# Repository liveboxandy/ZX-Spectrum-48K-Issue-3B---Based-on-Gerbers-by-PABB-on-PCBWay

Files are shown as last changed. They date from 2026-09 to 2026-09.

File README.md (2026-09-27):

# ZX-Spectrum 48K Issue 3B - Based on Gerbers by PABB on PCBWay

KiCAD created files for the ZX Spectrum 48K Issue 3B designed by Sinclair Research Ltd - Based on PABB Gerbers

Original Gerbers by PABB downloadable via PCBWay.

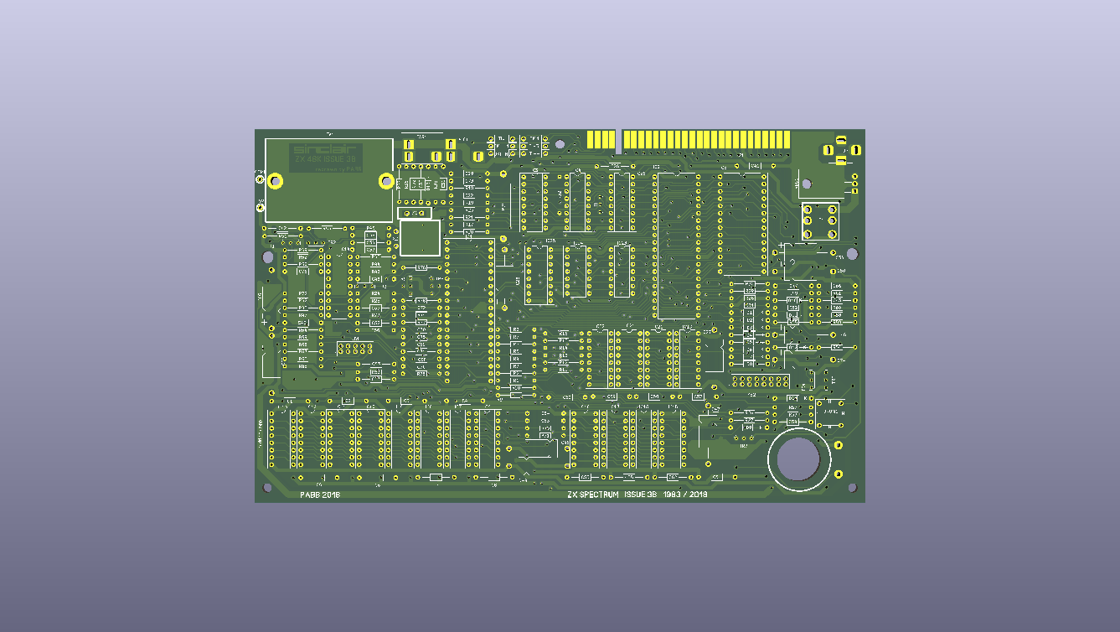
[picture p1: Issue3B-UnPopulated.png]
Unpopulated PCB


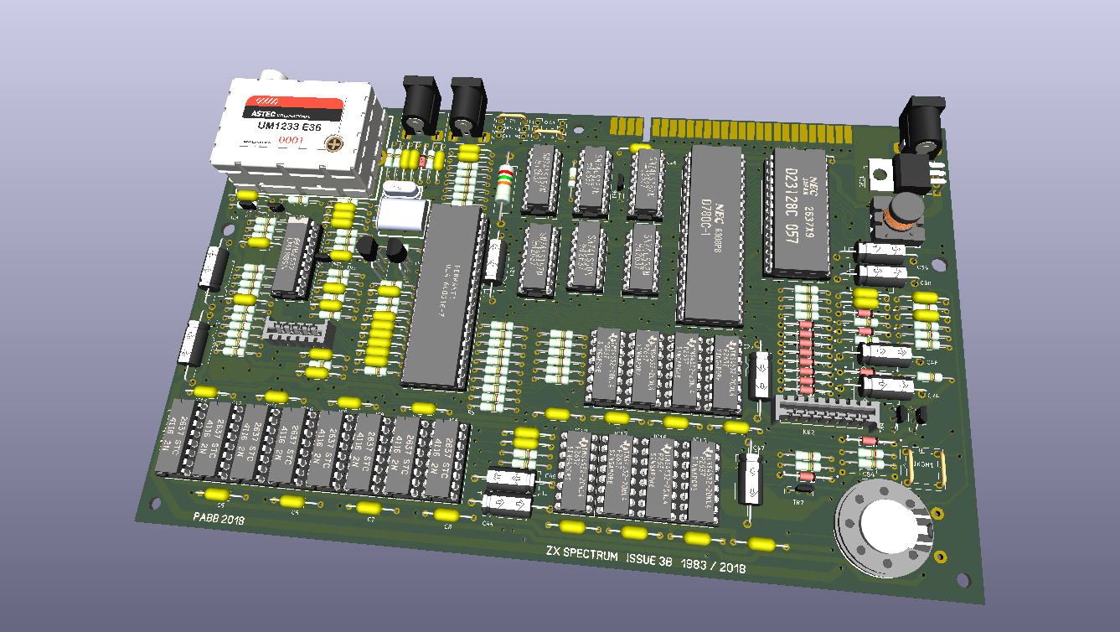
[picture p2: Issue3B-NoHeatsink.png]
Populated PCB No Heatsink


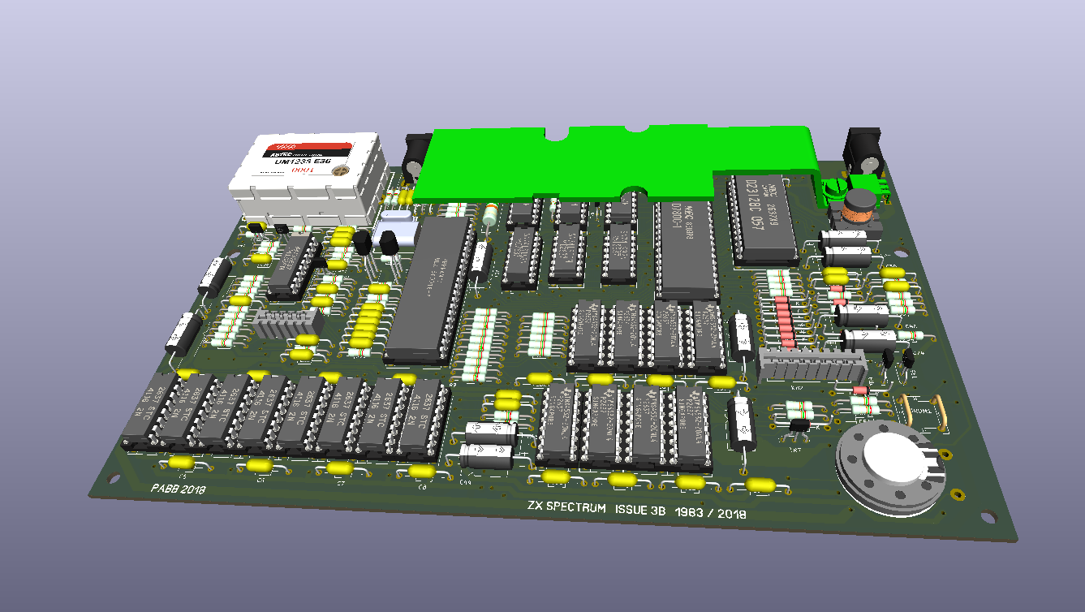
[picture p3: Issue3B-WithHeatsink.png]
Populated PCB With Heatsink


See https://www.pcbway.com/project/shareproject/ZX_Spectrum_48_Issue_3B_Redrawn.html

Only the gerbers are available on PCBWay. No Schematic.

Schematic created from available schematics with corrections using Service Guide mods and PCB layout. 

Where differences were seen the PCB layout took preference.

This was only done in order to create an assist in debugging.

I would NOT use these gerbers to get a PCB manufactured without a lot more checking first.

For the following ULA 6C001 make the following changes,

R47 to 1K,
R49 to 10K,
R56 to 1K,
R63 to 1K.

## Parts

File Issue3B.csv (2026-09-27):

Reference | Qty | Value | DNP | Exclude from BOM | Exclude from Board | Footprint | Datasheet
C1,C2,C3,C4,C5,C6,C7,C8,C26,C29,C30,C33,C40,C41,C42,C48,C55,C56,C57,C58,C59,C60,C61,C62,C66,C76 | 26 | 47nF |  |  |  | Mod:C_Axial_L3.8mm_D2.6mm_P12.70mm_Horizontal | https://www.vishay.com/doc?45164
C25 | 1 | 22uF |  |  |  | Mod:CP_Axial_L11.0mm_D6.0mm_P20.00mm_Horizontal
C27 | 1 | 1uF |  |  |  | Mod:CP_Axial_L11.0mm_D6.0mm_P20.00mm_Horizontal
C28,C34,C47,C50,C65 | 5 | 22uF |  |  |  | Mod:CP_Axial_L11.0mm_D6.0mm_P20.32mm_Horizontal | https://www.cde.com/resources/catalogs/TTA.pdf
C31,C32 | 2 | 100nF |  |  |  | Mod:C_Axial_L3.8mm_D2.6mm_P12.40mm_Horizontal | https://www.vishay.com/doc?45164
C35 | 1 | 10nF |  |  |  | Mod:C_Axial_L3.8mm_D2.6mm_P12.40mm_Horizontal | https://www.vishay.com/doc?45164
C37,C38 | 2 | 33pF |  |  |  | Mod:C_Axial_L3.8mm_D2.6mm_P12.70mm_Horizontal | https://www.vishay.com/doc?45164
C39 | 1 | 10nF |  |  |  | Mod:C_Axial_L3.8mm_D2.6mm_P12.70mm_Horizontal | https://www.vishay.com/doc?45164
C43,C68,C69,C70,C71,C75,C77 | 7 | 100nF |  |  |  | Mod:C_Axial_L3.8mm_D2.6mm_P12.70mm_Horizontal | https://www.vishay.com/doc?45164
C44,C45 | 2 | 100uF |  |  |  | Mod:CP_Axial_L11.0mm_D6.0mm_P20.32mm_Horizontal | https://www.cde.com/resources/catalogs/TTA.pdf
C46 | 1 | 1uF |  |  |  | Mod:CP_Axial_L11.0mm_D6.0mm_P20.32mm_Horizontal | https://www.cde.com/resources/catalogs/TTA.pdf
C49 | 1 | 560pF |  |  |  | Mod:C_Axial_L3.8mm_D2.6mm_P12.70mm_Horizontal | https://www.vishay.com/doc?45164
C52,C53 | 2 | 150pF |  |  |  | Mod:C_Axial_L3.8mm_D2.6mm_P12.70mm_Horizontal | https://www.vishay.com/doc?45164
C54 | 1 | 470pF | DNP |  |  | Mod:C_Axial_L3.8mm_D2.6mm_P12.70mm_Horizontal | https://www.vishay.com/doc?45164
C63 | 1 | 47pF |  |  |  | Mod:C_Axial_L3.8mm_D2.6mm_P12.70mm_Horizontal | https://www.vishay.com/doc?45164
C64,C67 | 2 | 100pF |  |  |  | Mod:C_Axial_L3.8mm_D2.6mm_P12.70mm_Horizontal | https://www.vishay.com/doc?45164
C72,C73 | 2 | 16pF |  |  |  | Mod:C_Axial_L3.8mm_D2.6mm_P12.70mm_Horizontal | https://www.vishay.com/doc?45164
C74 | 1 | 4.7uF |  |  |  | Mod:CP_Axial_L11.0mm_D6.0mm_P20.32mm_Horizontal | https://www.cde.com/resources/catalogs/TTA.pdf
D1,D2,D3,D4,D5,D6,D7,D8,D9,D11,D12 | 11 | 1N4148 |  |  |  | Mod:D_DO-35_SOD27_P12.70mm_Horizontal
D13 | 1 | 1N4148 |  |  |  | Mod:D_DO-35_SOD27_P12.40mm_Horizontal
D15 | 1 | BA157 |  |  |  | Mod:D_DO-35_SOD27_P12.70mm_Horizontal
D16 | 1 | BZX85C5V1 |  |  |  | Mod:D_DO-35_SOD27_P12.70mm_Horizontal
E1 | 1 | Edge_Connector |  |  |  | Mod:Edge Connector
EAR1 | 1 | EAR1 |  |  |  | Mod:3.5mm_socket
IC1 | 1 | ULA |  |  |  | Mod:DIP-40_W15.24mm_Socket
IC2 | 1 | Z80 |  |  |  | Mod:DIP-40_W15.24mm_Socket
IC3,IC4,IC25,IC26 | 4 | LS157 |  |  |  | Mod:DIP-16_W7.62mm_Socket
IC5 | 1 | ROM |  |  |  | Mod:DIP-28_W15.24mm_Socket
IC6,IC7,IC8,IC9,IC10,IC11,IC12,IC13 | 8 | 4116 |  |  |  | Mod:DIP-16_W7.62mm_Socket
IC14 | 1 | LM1889 |  |  |  | Mod:DIP-18_W7.62mm_Socket
IC15,IC16,IC17,IC18,IC19,IC20,IC21,IC22 | 8 | 4532 |  |  |  | Mod:DIP-16_W7.62mm_Socket
IC23 | 1 | LS32 |  |  |  | Mod:DIP-14_W7.62mm_Socket | http://www.ti.com/lit/gpn/sn74ls00
IC24 | 1 | LS00 |  |  |  | Mod:DIP-14_W7.62mm_Socket | http://www.ti.com/lit/gpn/sn74ls00
J7 | 1 | Barrel_Jack_MountingPin |  |  |  | Mod:BarrelJack_Horizontal | ~
JROM1 | 1 | JROM |  |  |  | Mod:ROM_WireLink
KB1 | 1 | Keyboard5 |  |  |  | Mod:Keyboard5
KB2 | 1 | Keyboard8 |  |  |  | Mod:Keyboard8
LS1 | 1 | Speaker |  |  |  | Mod:Speaker | ~
MIC1 | 1 | MIC1 |  |  |  | Mod:3.5mm_socket
OKI-H1 | 1 | OKI-H |  |  |  | Mod:WireLink
OKI-L1 | 1 | OKI-L |  |  |  | Mod:WireLink
OKI1 | 1 | OKI |  |  |  | Mod:WireLink
R1,R2,R3,R4,R5,R6,R7,R8,R26,R27,R78 | 11 | 470 |  |  |  | Mod:R_Yageo_L3.6mm_D1.6mm_P12.70mm_Horizontal
R9,R10,R11,R12,R13,R14,R15,R16 | 8 | 8k2 |  |  |  | Mod:R_Yageo_L3.6mm_D1.6mm_P12.70mm_Horizontal
R17,R18,R19,R20,R21,R22,R23,R57 | 8 | 330 |  |  |  | Mod:R_Yageo_L3.6mm_D1.6mm_P12.70mm_Horizontal
R24,R73 | 2 | 1k |  |  |  | Mod:R_Yageo_L3.6mm_D1.6mm_P12.70mm_Horizontal
R25 | 1 | 180 |  |  |  | Mod:R_Yageo_L3.6mm_D1.6mm_P12.70mm_Horizontal
R28,R29,R30,R49,R65,R66,R67,R68,R69,R72,R74,R75 | 12 | 10K |  |  |  | Mod:R_Yageo_L3.6mm_D1.6mm_P12.70mm_Horizontal
R31 | 1 | 220K |  |  |  | Mod:R_Yageo_L3.6mm_D1.6mm_P12.70mm_Horizontal
R32 | 1 | 100 |  |  |  | Mod:R_Yageo_L3.6mm_D1.6mm_P12.70mm_Horizontal
R33 | 1 | 680 |  |  |  | Mod:R_Yageo_L3.6mm_D1.6mm_P12.70mm_Horizontal
R34 | 1 | 15 |  |  |  | Mod:R_Axial_DIN0516_L15.5mm_D5.0mm_P22.60mm_Horizontal
R35 | 1 | 10K |  |  |  | Mod:R_Yageo_L3.6mm_D1.6mm_P12.40mm_Horizontal
R36 | 1 | 680 |  |  |  | Mod:R_Yageo_L3.6mm_D1.6mm_P12.40mm_Horizontal
R37 | 1 | 1K |  |  |  | Mod:R_Yageo_L3.6mm_D1.6mm_P12.40mm_Horizontal
R42,R45,R46,R47,R56,R58,R63,R76,R77 | 9 | 1K |  |  |  | Mod:R_Yageo_L3.6mm_D1.6mm_P12.70mm_Horizontal
R43 | 1 | 3K |  |  |  | Mod:R_Yageo_L3.6mm_D1.6mm_P12.70mm_Horizontal
R44 | 1 | 5K1 |  |  |  | Mod:R_Yageo_L3.6mm_D1.6mm_P12.70mm_Horizontal
R48,R51,R52 | 3 | 2K2 |  |  |  | Mod:R_Yageo_L3.6mm_D1.6mm_P12.70mm_Horizontal
R50 | 1 | 4K7 |  |  |  | Mod:R_Yageo_L3.6mm_D1.6mm_P12.70mm_Horizontal
R53 | 1 | 390R |  |  |  | Mod:R_Yageo_L3.6mm_D1.6mm_P12.70mm_Horizontal
R54 | 1 | 100K |  |  |  | Mod:R_Yageo_L3.6mm_D1.6mm_P12.70mm_Horizontal
R55 | 1 | 56 |  |  |  | Mod:R_Yageo_L3.6mm_D1.6mm_P12.70mm_Horizontal
R59 | 1 | 1K8 |  |  |  | Mod:R_Yageo_L3.6mm_D1.6mm_P12.70mm_Horizontal
R60 | 1 | 68R |  |  |  | Mod:R_Yageo_L3.6mm_D1.6mm_P12.70mm_Horizontal
R61,R62,R64 | 3 | 15 |  |  |  | Mod:R_Yageo_L3.6mm_D1.6mm_P12.70mm_Horizontal
R70,R71 | 2 | 220 |  |  |  | Mod:R_Yageo_L3.6mm_D1.6mm_P12.70mm_Horizontal
REG1 | 1 | L7805 |  |  |  | Mod:TO-220-3_Horizontal_TabDown
T1 | 1 | Transformer_1P_1S |  |  |  | Mod:Coil
TI-3 | 1 | TI-3 |  |  |  | Mod:WireLink
TI-4 | 1 | TI-4 |  |  |  | Mod:WireLink
TI1 | 1 | TI |  |  |  | Mod:WireLink
TR1,TR2,TR3,TR6 | 4 | ZTX313 |  |  |  | Mod:TO-92Flat
TR4 | 1 | ZTX650 |  |  |  | Mod:TO-92Flat
TR5 | 1 | ZTX315 |  |  |  | Mod:TO-92Flat
TR7 | 1 | ZTX450 |  |  |  | Mod:TO-92Flat
TR8,TR9 | 2 | BC184 |  |  |  | Mod:TR9
TV1 | 1 | TV |  |  |  | Mod:Modulator
X1 | 1 | 14Mhz |  |  |  | Mod:X1
X2 | 1 | 4.43Mhz |  |  |  | Mod:X2

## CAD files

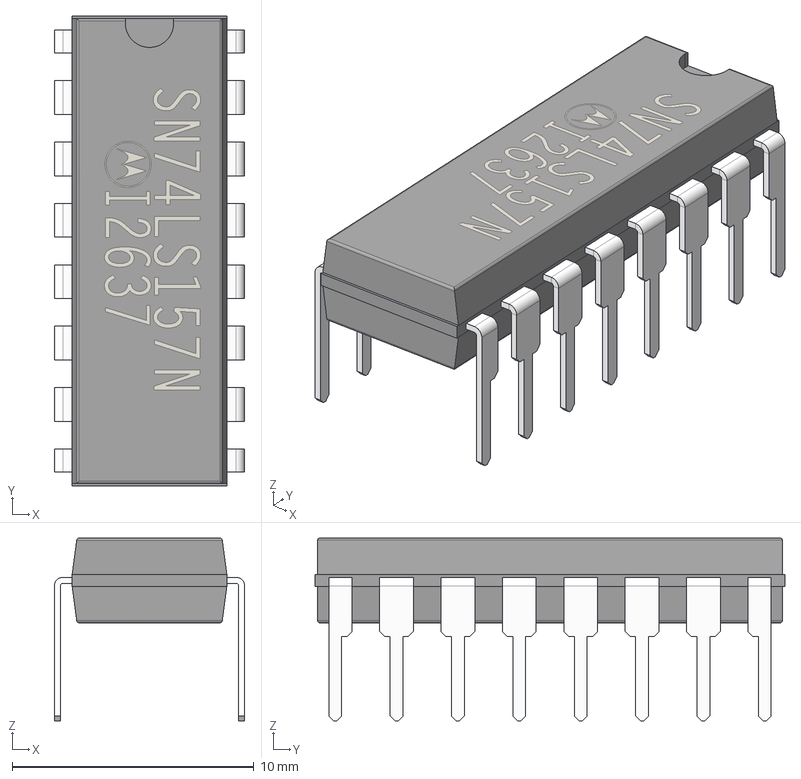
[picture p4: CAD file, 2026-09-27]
STPS/MOT_SN74LS157N.step
7.87 x 19.5 x 7.57 mm
Basic - DIP 7.62 v3
DIP Pin 14-20 v3
DIP Pin 14-20 v3(Mirror)

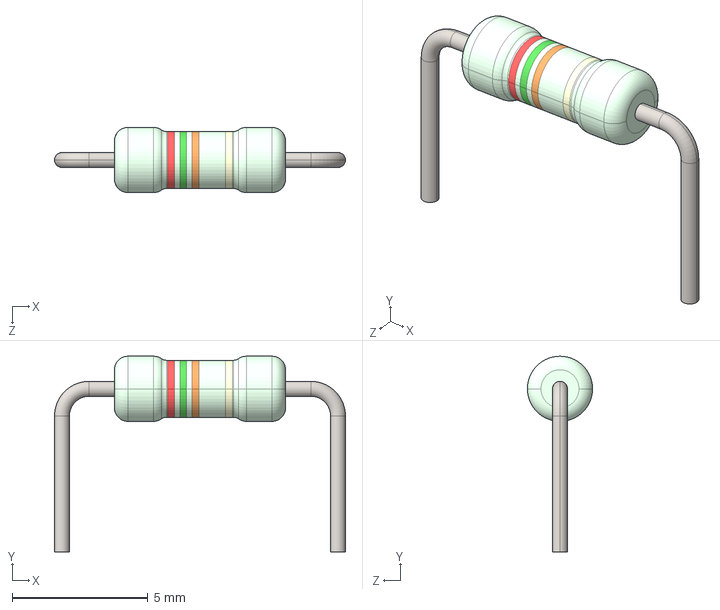
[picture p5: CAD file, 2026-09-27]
STPS/Resistor-0207-6.3x2.4x10.16.STEP
10.7 x 7.20 x 2.40 mm

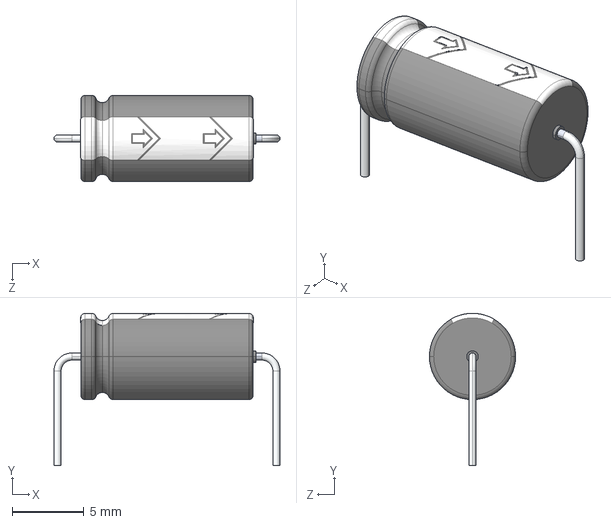
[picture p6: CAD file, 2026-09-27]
STPS/CP 13x5x0.5x15.24.STEP
15.7 x 10.6 x 6.00 mm

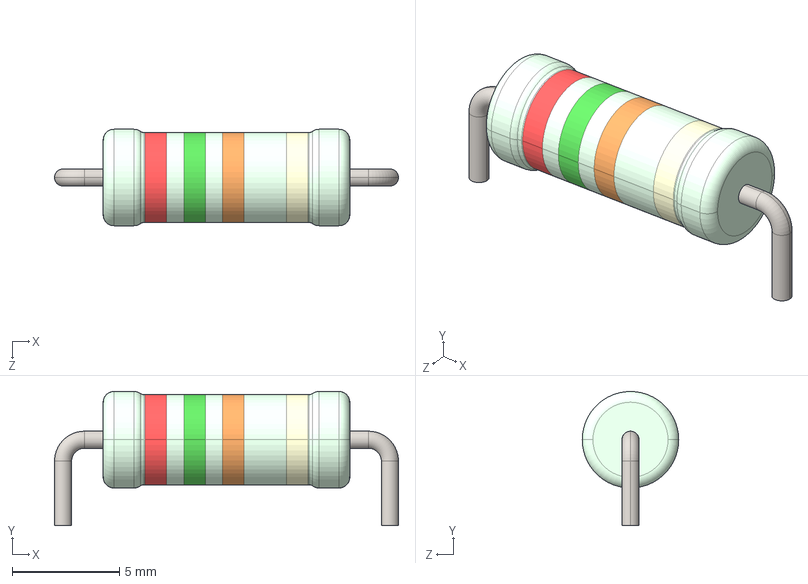
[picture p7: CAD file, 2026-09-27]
STPS/Resistor-0414-11.5x4.5x15.24x3.STEP
16.0 x 6.25 x 4.50 mm

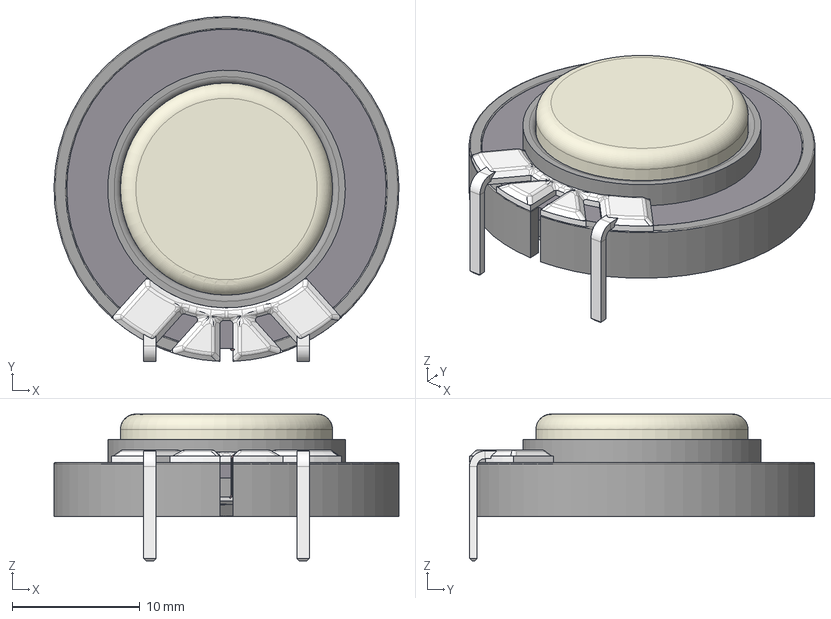
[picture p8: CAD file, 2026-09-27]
STPS/ZX Spectrum 48k Speaker.step
27.0 x 27.0 x 11.5 mm
Magnet
Soldering
pins
Plastic Film
Copper Wire

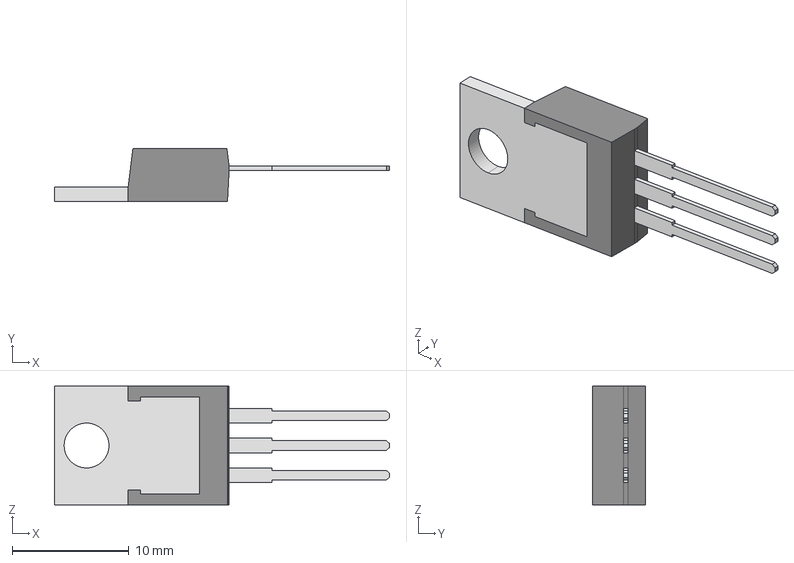
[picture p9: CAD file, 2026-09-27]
STPS/LM7805CT_NOPB.stp
28.7 x 4.57 x 10.2 mm
T03B_BODY
T03B_LEAD x 3
T03B_HS

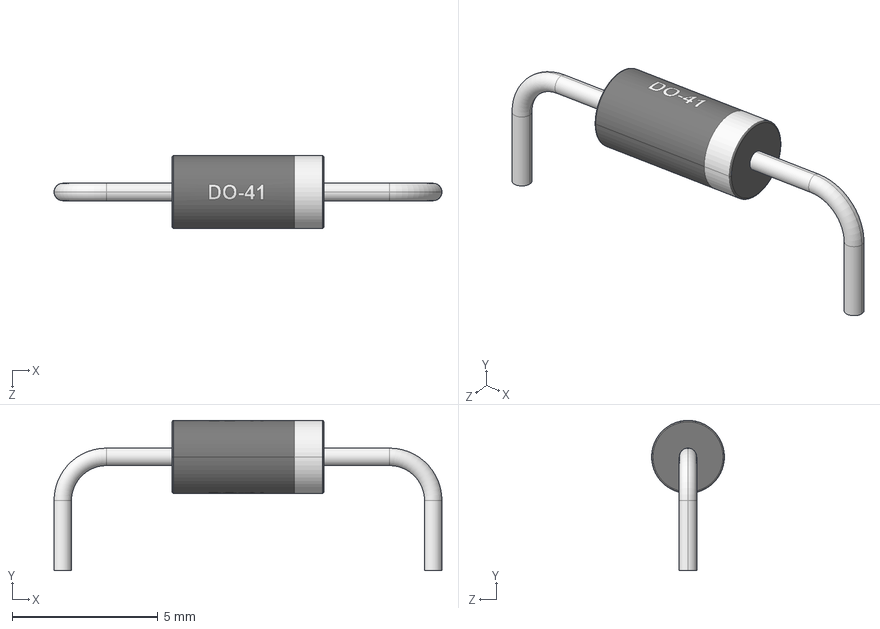
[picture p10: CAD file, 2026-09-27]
STPS/DO-41-5.10x2.60x12.70.STEP
13.3 x 5.15 x 2.50 mm

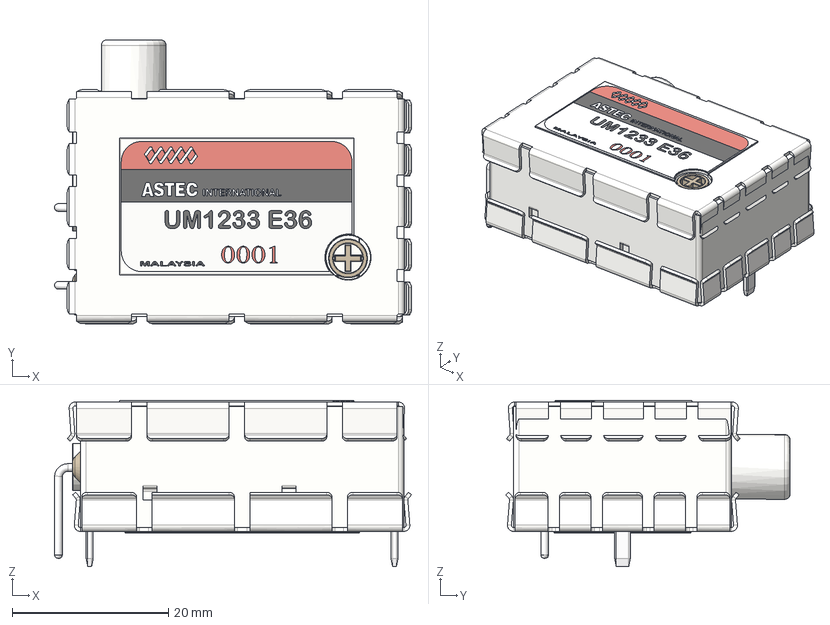
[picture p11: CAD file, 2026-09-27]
STPS/RF MOD Astec UM1233 E36.step
45.7 x 36.4 x 21.3 mm
Metal Body
Lid Bottom
Lid Top

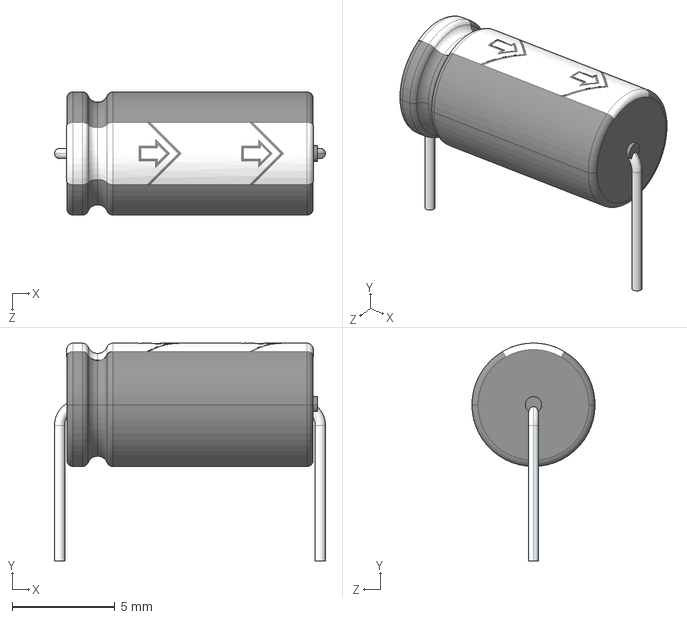
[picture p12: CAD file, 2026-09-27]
STPS/CP 13x5x0.5x12.70.STEP
13.2 x 10.6 x 6.00 mm

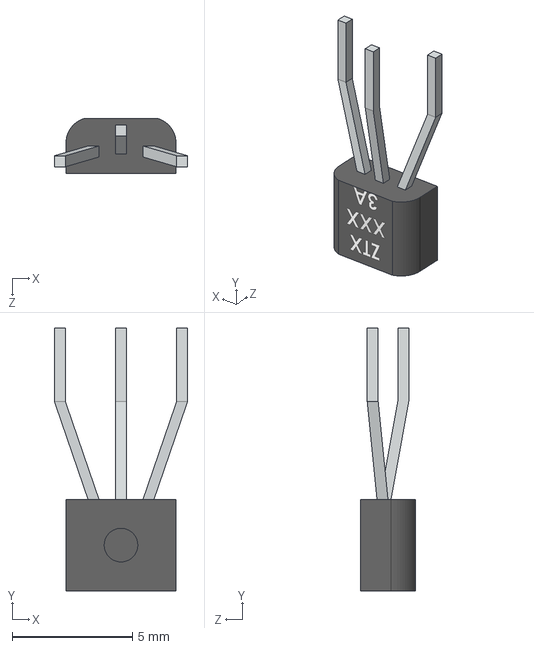
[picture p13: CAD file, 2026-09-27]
STPS/ZTXxxx Kinked Triangle.STEP
5.54 x 10.9 x 2.29 mm

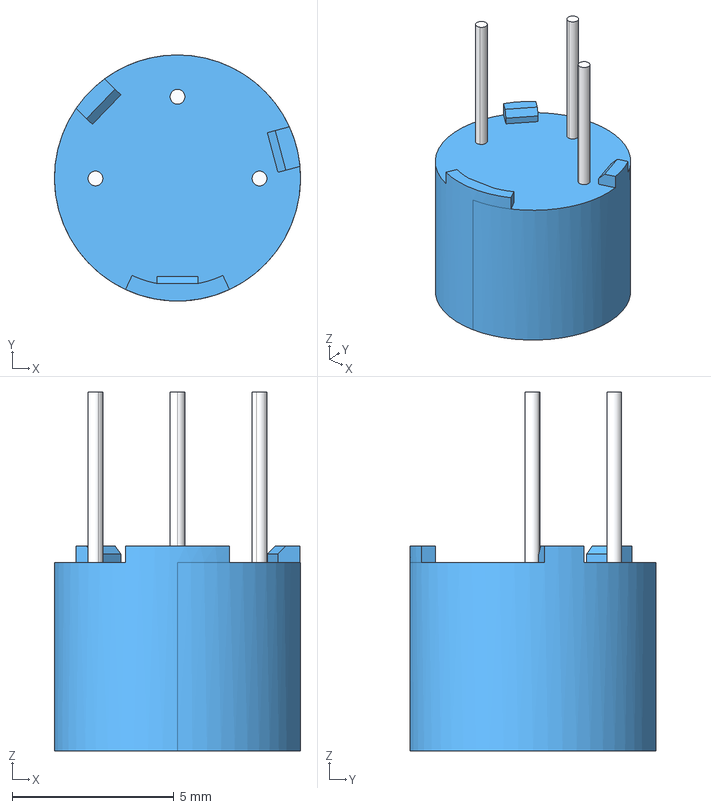
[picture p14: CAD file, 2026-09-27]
STPS/Pot 3339P-1-222LF.stp
7.62 x 7.62 x 11.1 mm

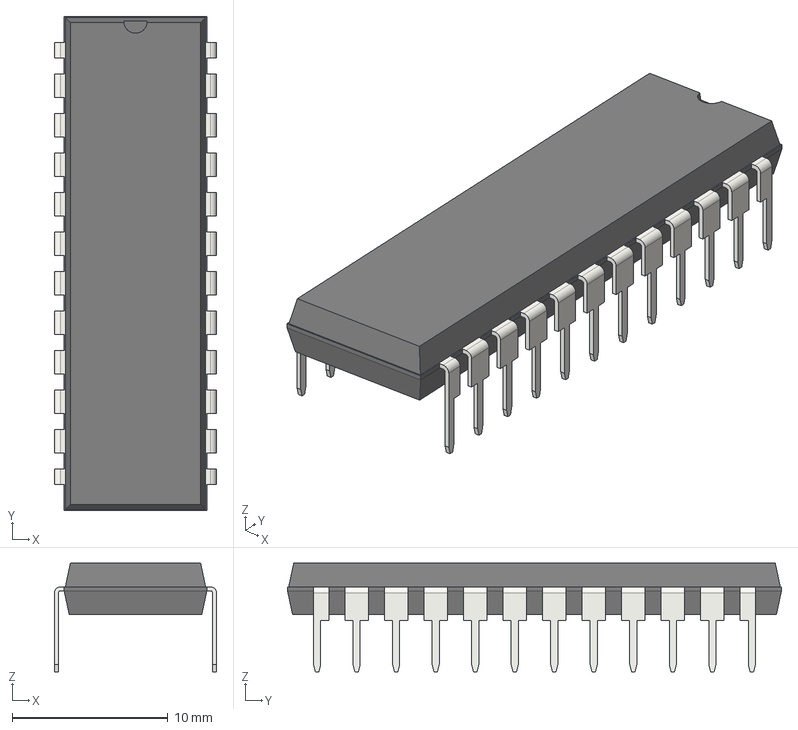
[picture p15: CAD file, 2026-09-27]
STPS/DIP-24_W10.16mm.step
10.4 x 31.8 x 6.98 mm

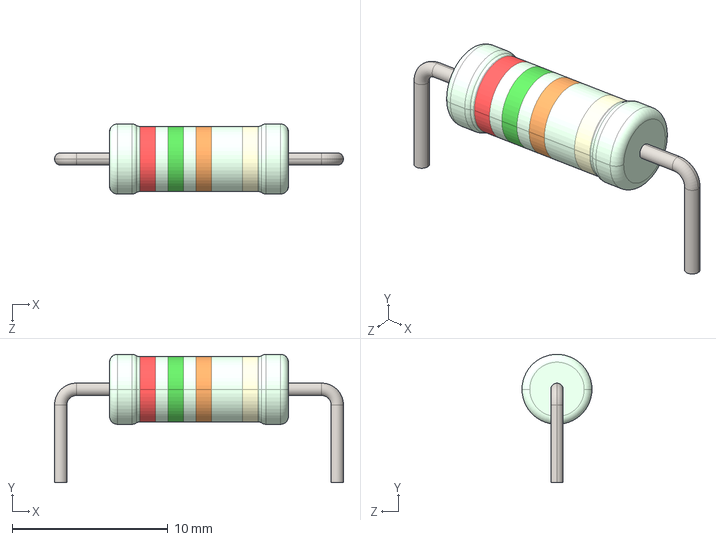
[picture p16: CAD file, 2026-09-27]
STPS/Resistor-0414-11.5x4.5x17.78.STEP
18.6 x 8.25 x 4.50 mm

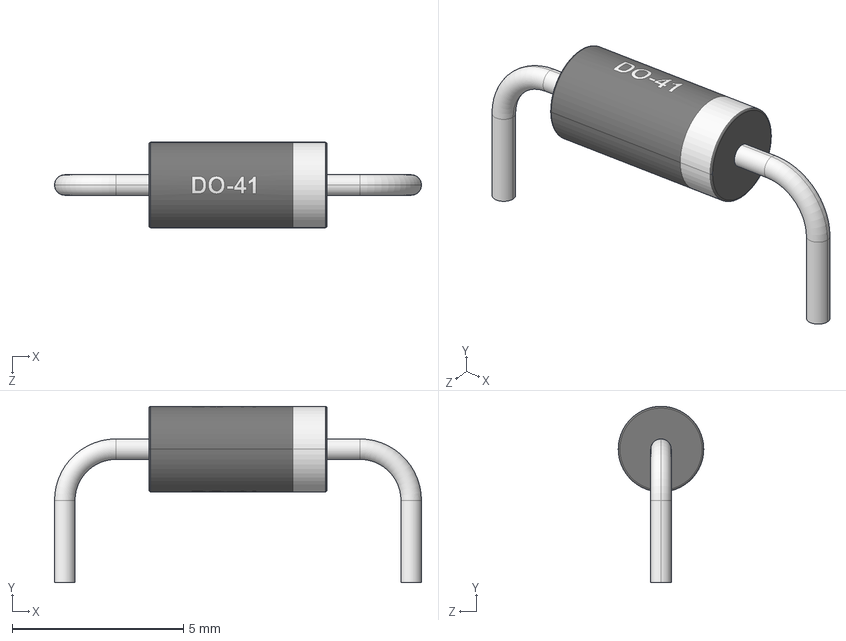
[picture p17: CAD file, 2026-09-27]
STPS/DO-41-5.10x2.60x10.12.STEP
10.7 x 5.15 x 2.50 mm

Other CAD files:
STPS/TI_TMS4532.step
STPS/MOT_SN74LS32N.step
STPS/CONN-TH_5P-P2.54_520315-5.step
STPS/NS_LM1889N.step
STPS/13.34x13.34 Bobin.STEP
STPS/22-02-3053.stp
STPS/22-02-3083.stp
STPS/409HS-1K.stp
STPS/5-520315-5.stp
STPS/AUDIO_JACK_3PIN.step
STPS/Axial Capacitor Old.step
STPS/Axial Capacitor.step
STPS/BarrelJack_Horizontal.step
STPS/CMS-1805-24SP.stp
STPS/COIL_L1.step
STPS/CONN-TH_8P-P2.54_520315-8.step
STPS/CONN_5-520315-8_TYC.stp
STPS/CP 13x5x0.5x17.78.STEP
STPS/CP 13x5x0.5x20.32.STEP
STPS/CP 13x5x0.5x22.86.STEP
STPS/CP 13x5x0.5x25.40.STEP
STPS/Capacitor Ceramic No Polarity axial 10.16.STEP
STPS/Capacitor Ceramic No Polarity axial 12.70.STEP
STPS/Capacitor Ceramic No Polarity axial 15.24.STEP
STPS/Capacitor Ceramic No Polarity axial 17.72.STEP
STPS/Capacitor Ceramic No Polarity axial 20.32.STEP
STPS/Capacitor Ceramic No Polarity axial 22.86.STEP
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

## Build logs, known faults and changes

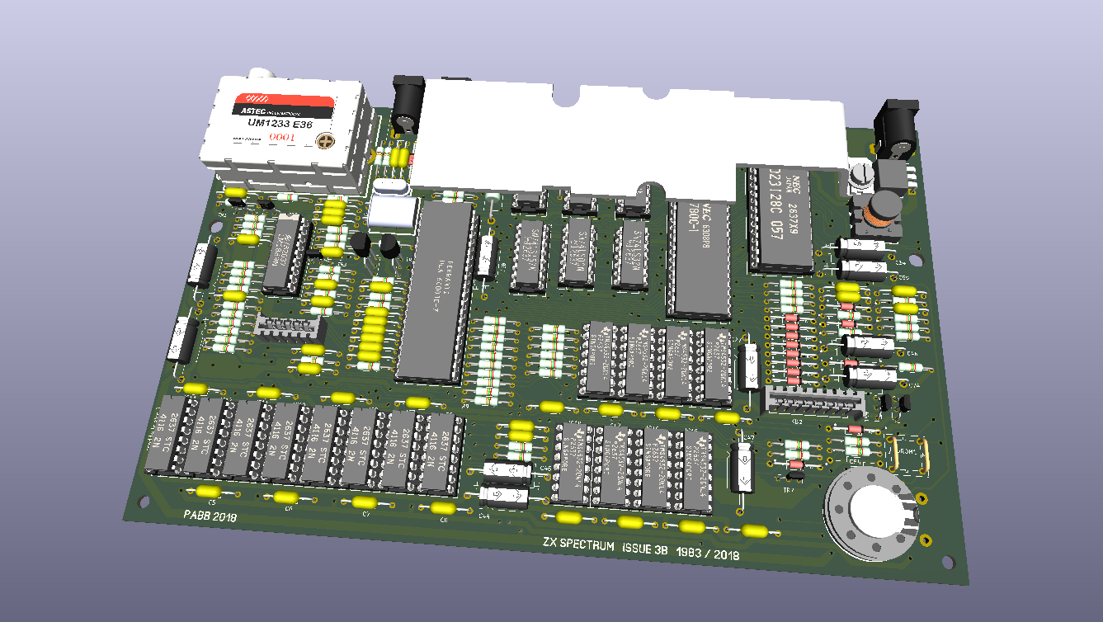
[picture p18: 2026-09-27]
Issue3B.png

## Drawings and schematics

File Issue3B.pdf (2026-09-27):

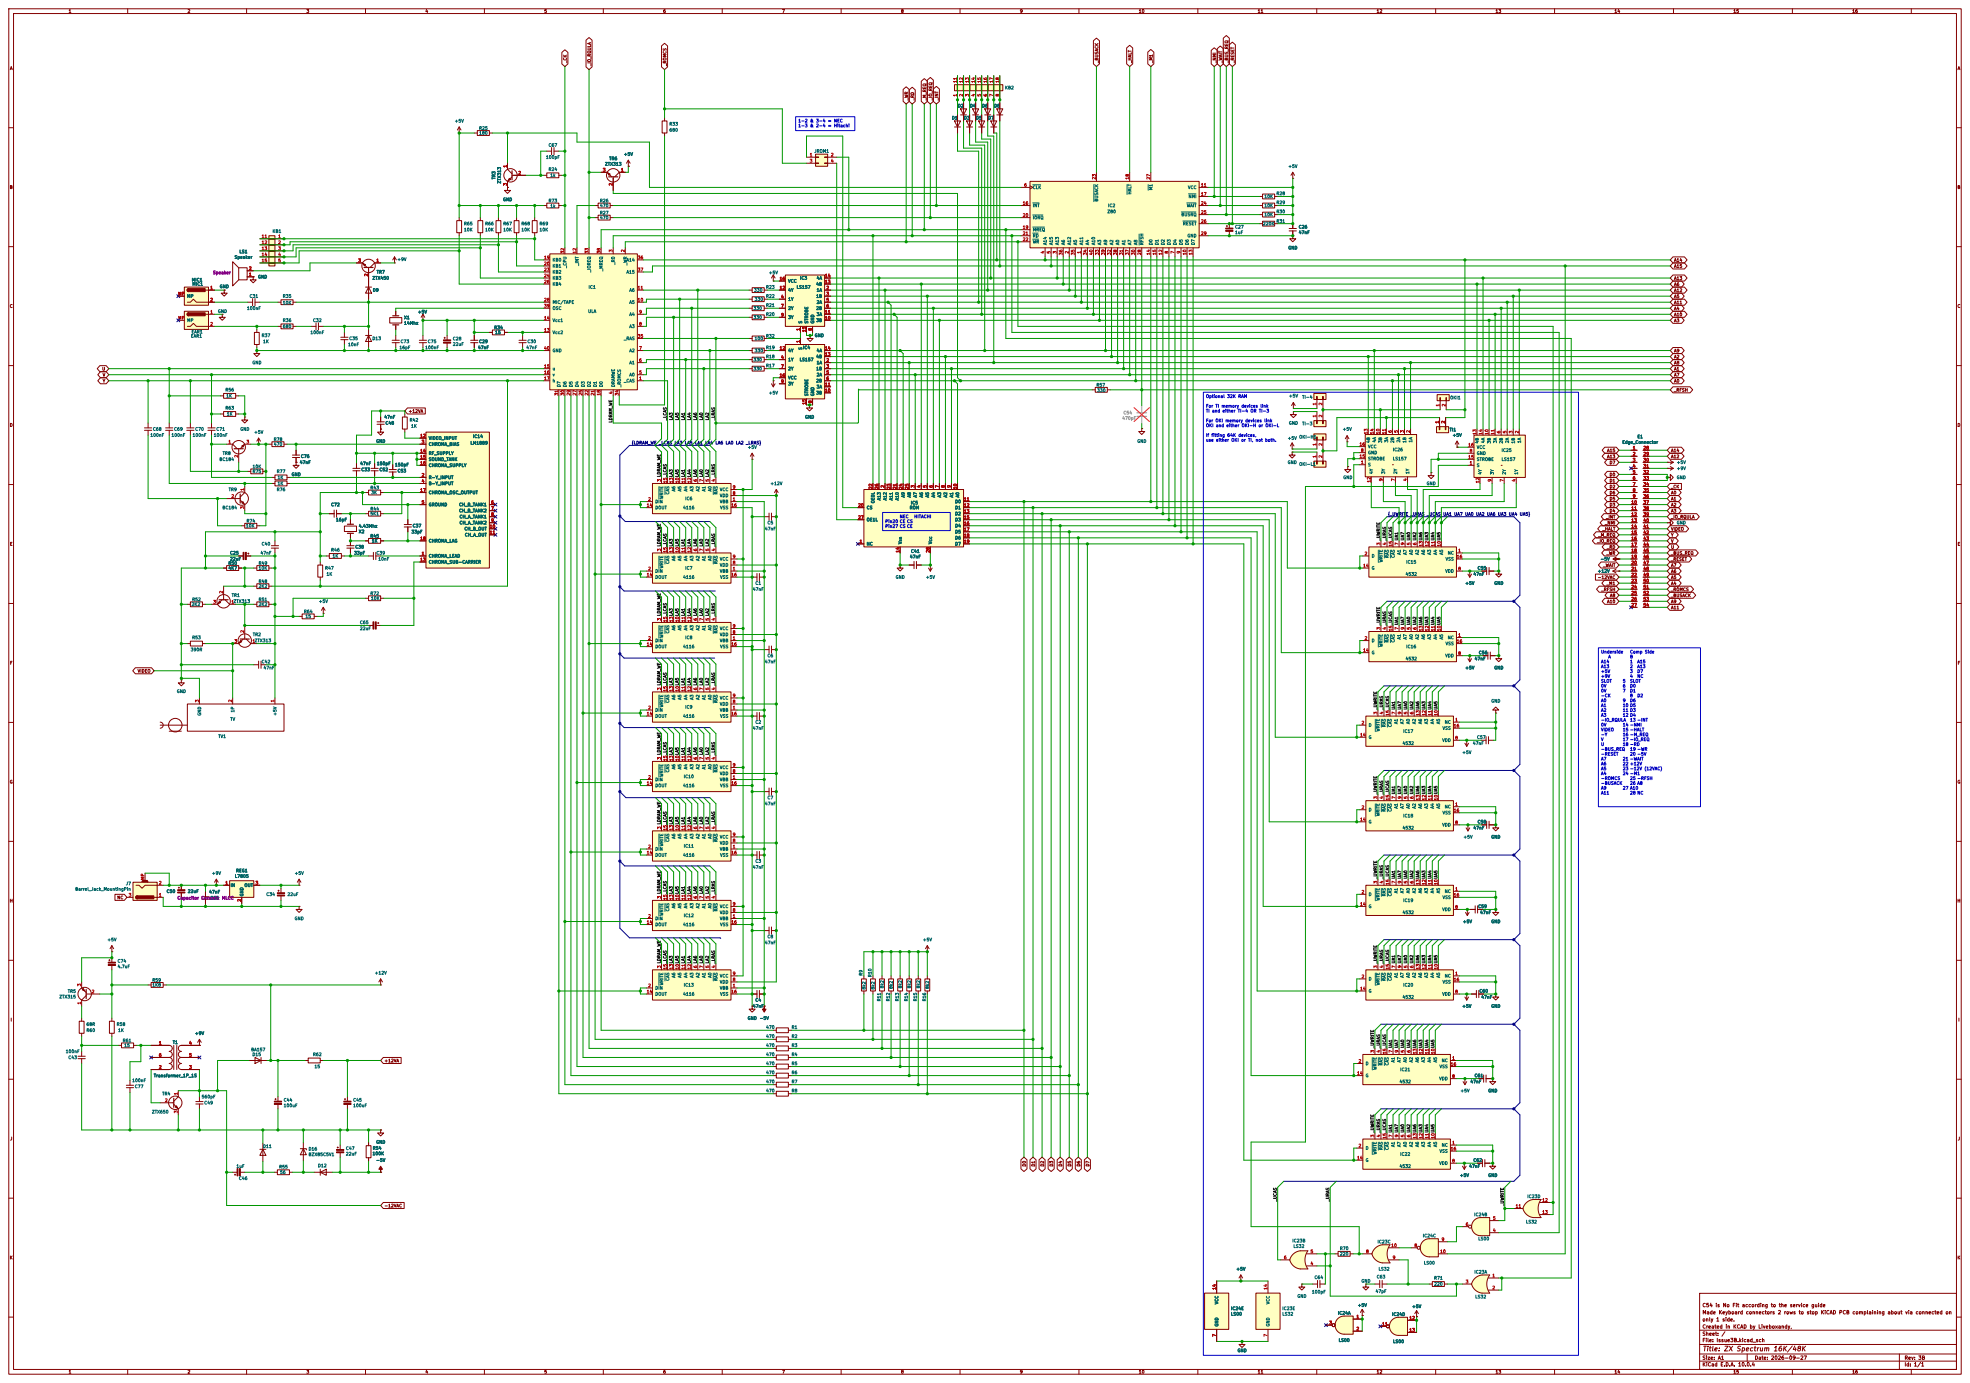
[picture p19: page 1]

For TI memory devices link
TI and either TI-4 OR TI-3

For OKI memory devices link OKI and either OKI-H or OKI-L

IC5 ROM
NEC HITACHI Pin20 CE CS Pin27 CS CE

VDD 4532 | 8 A7

Made Keyboard connectors 2 rows to stop KiCAD PCB complaining about via connected on C54 is No Fit according to the service guide

only 1 side.
Created in KCAD by Liveboxandy,
Sheet: /
File: Issue3B.kicad_sch
Title: ZX Spectrum 16K/48K

Size: A1 | Rev: 3B
KiCad E.D.A. 10.0.4 | Id: 1/1

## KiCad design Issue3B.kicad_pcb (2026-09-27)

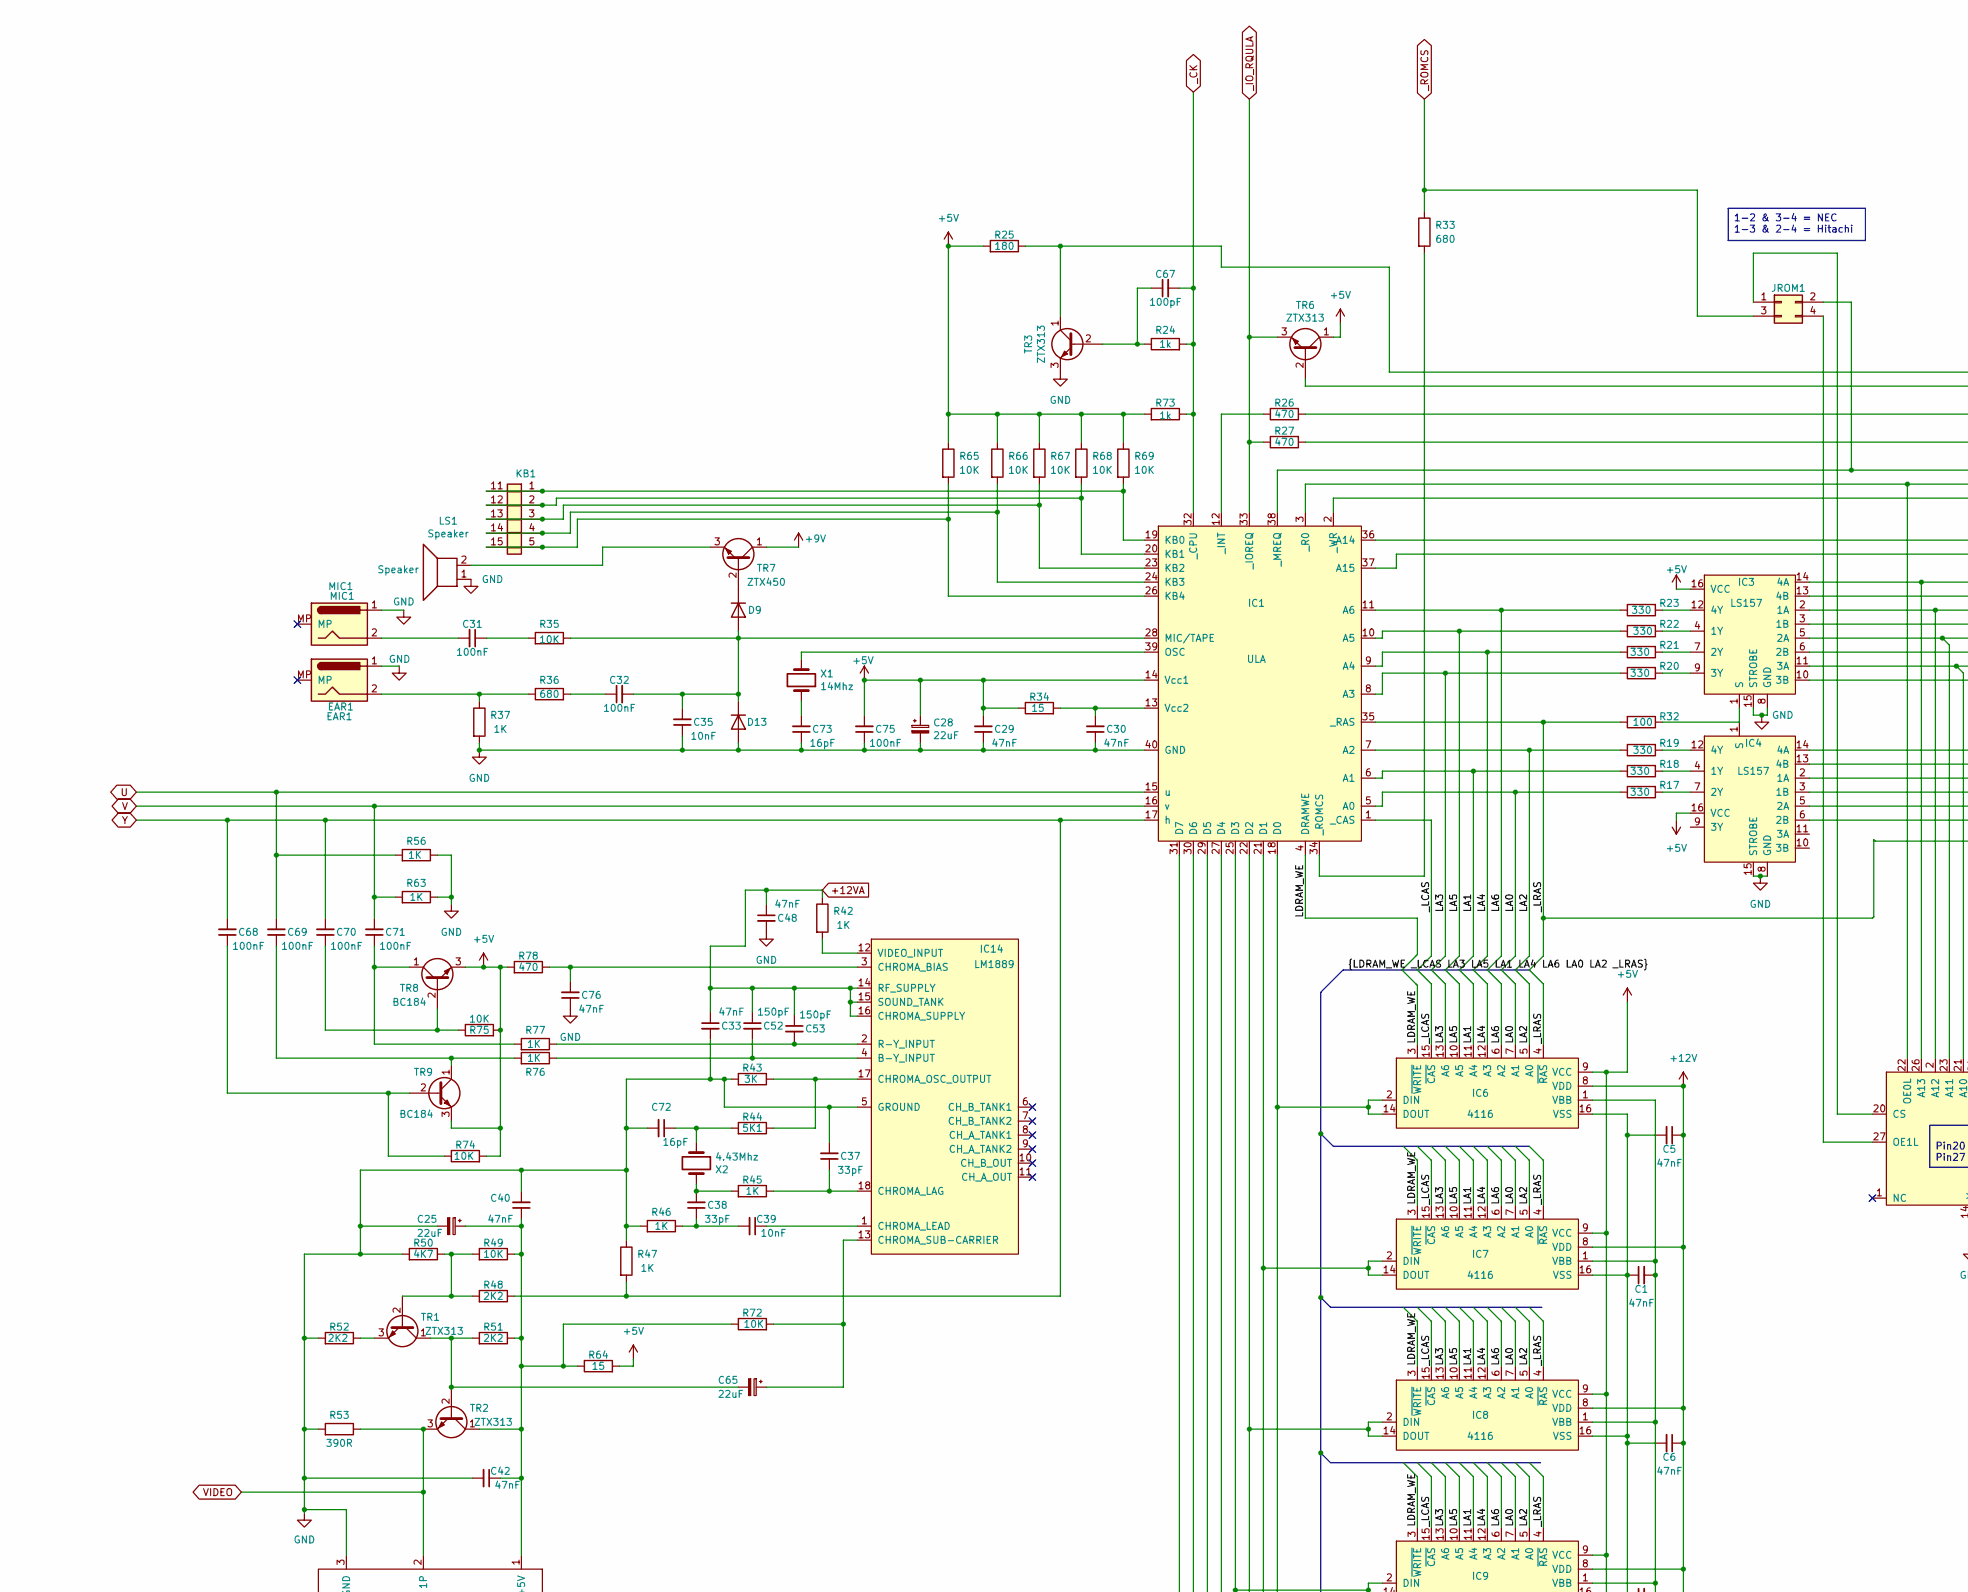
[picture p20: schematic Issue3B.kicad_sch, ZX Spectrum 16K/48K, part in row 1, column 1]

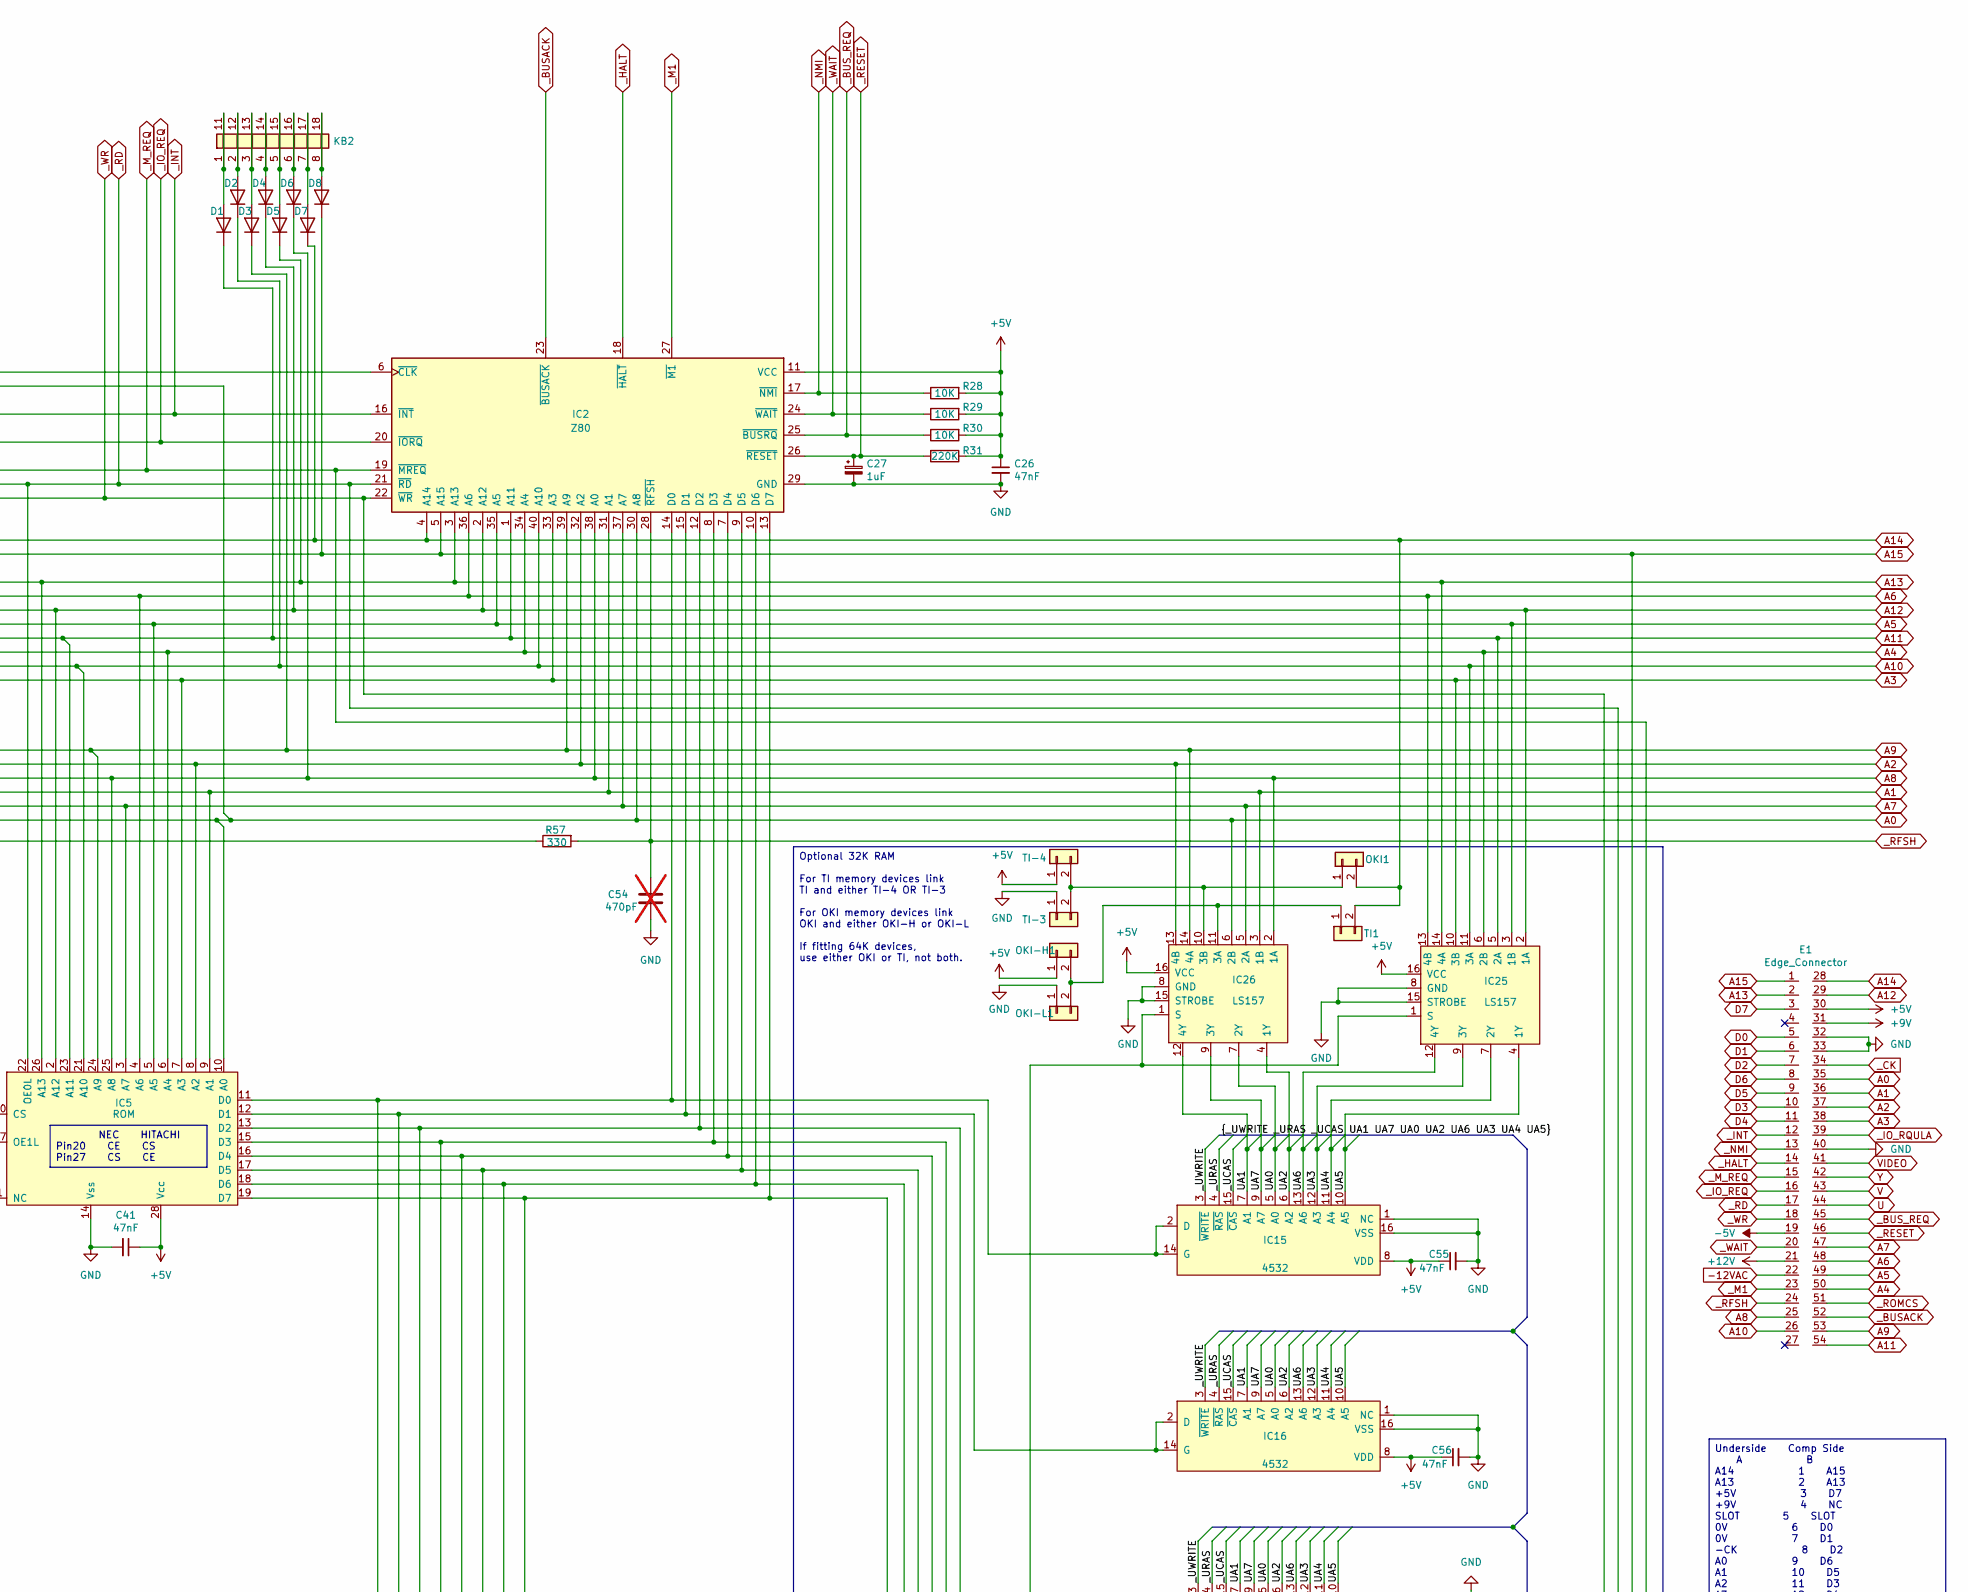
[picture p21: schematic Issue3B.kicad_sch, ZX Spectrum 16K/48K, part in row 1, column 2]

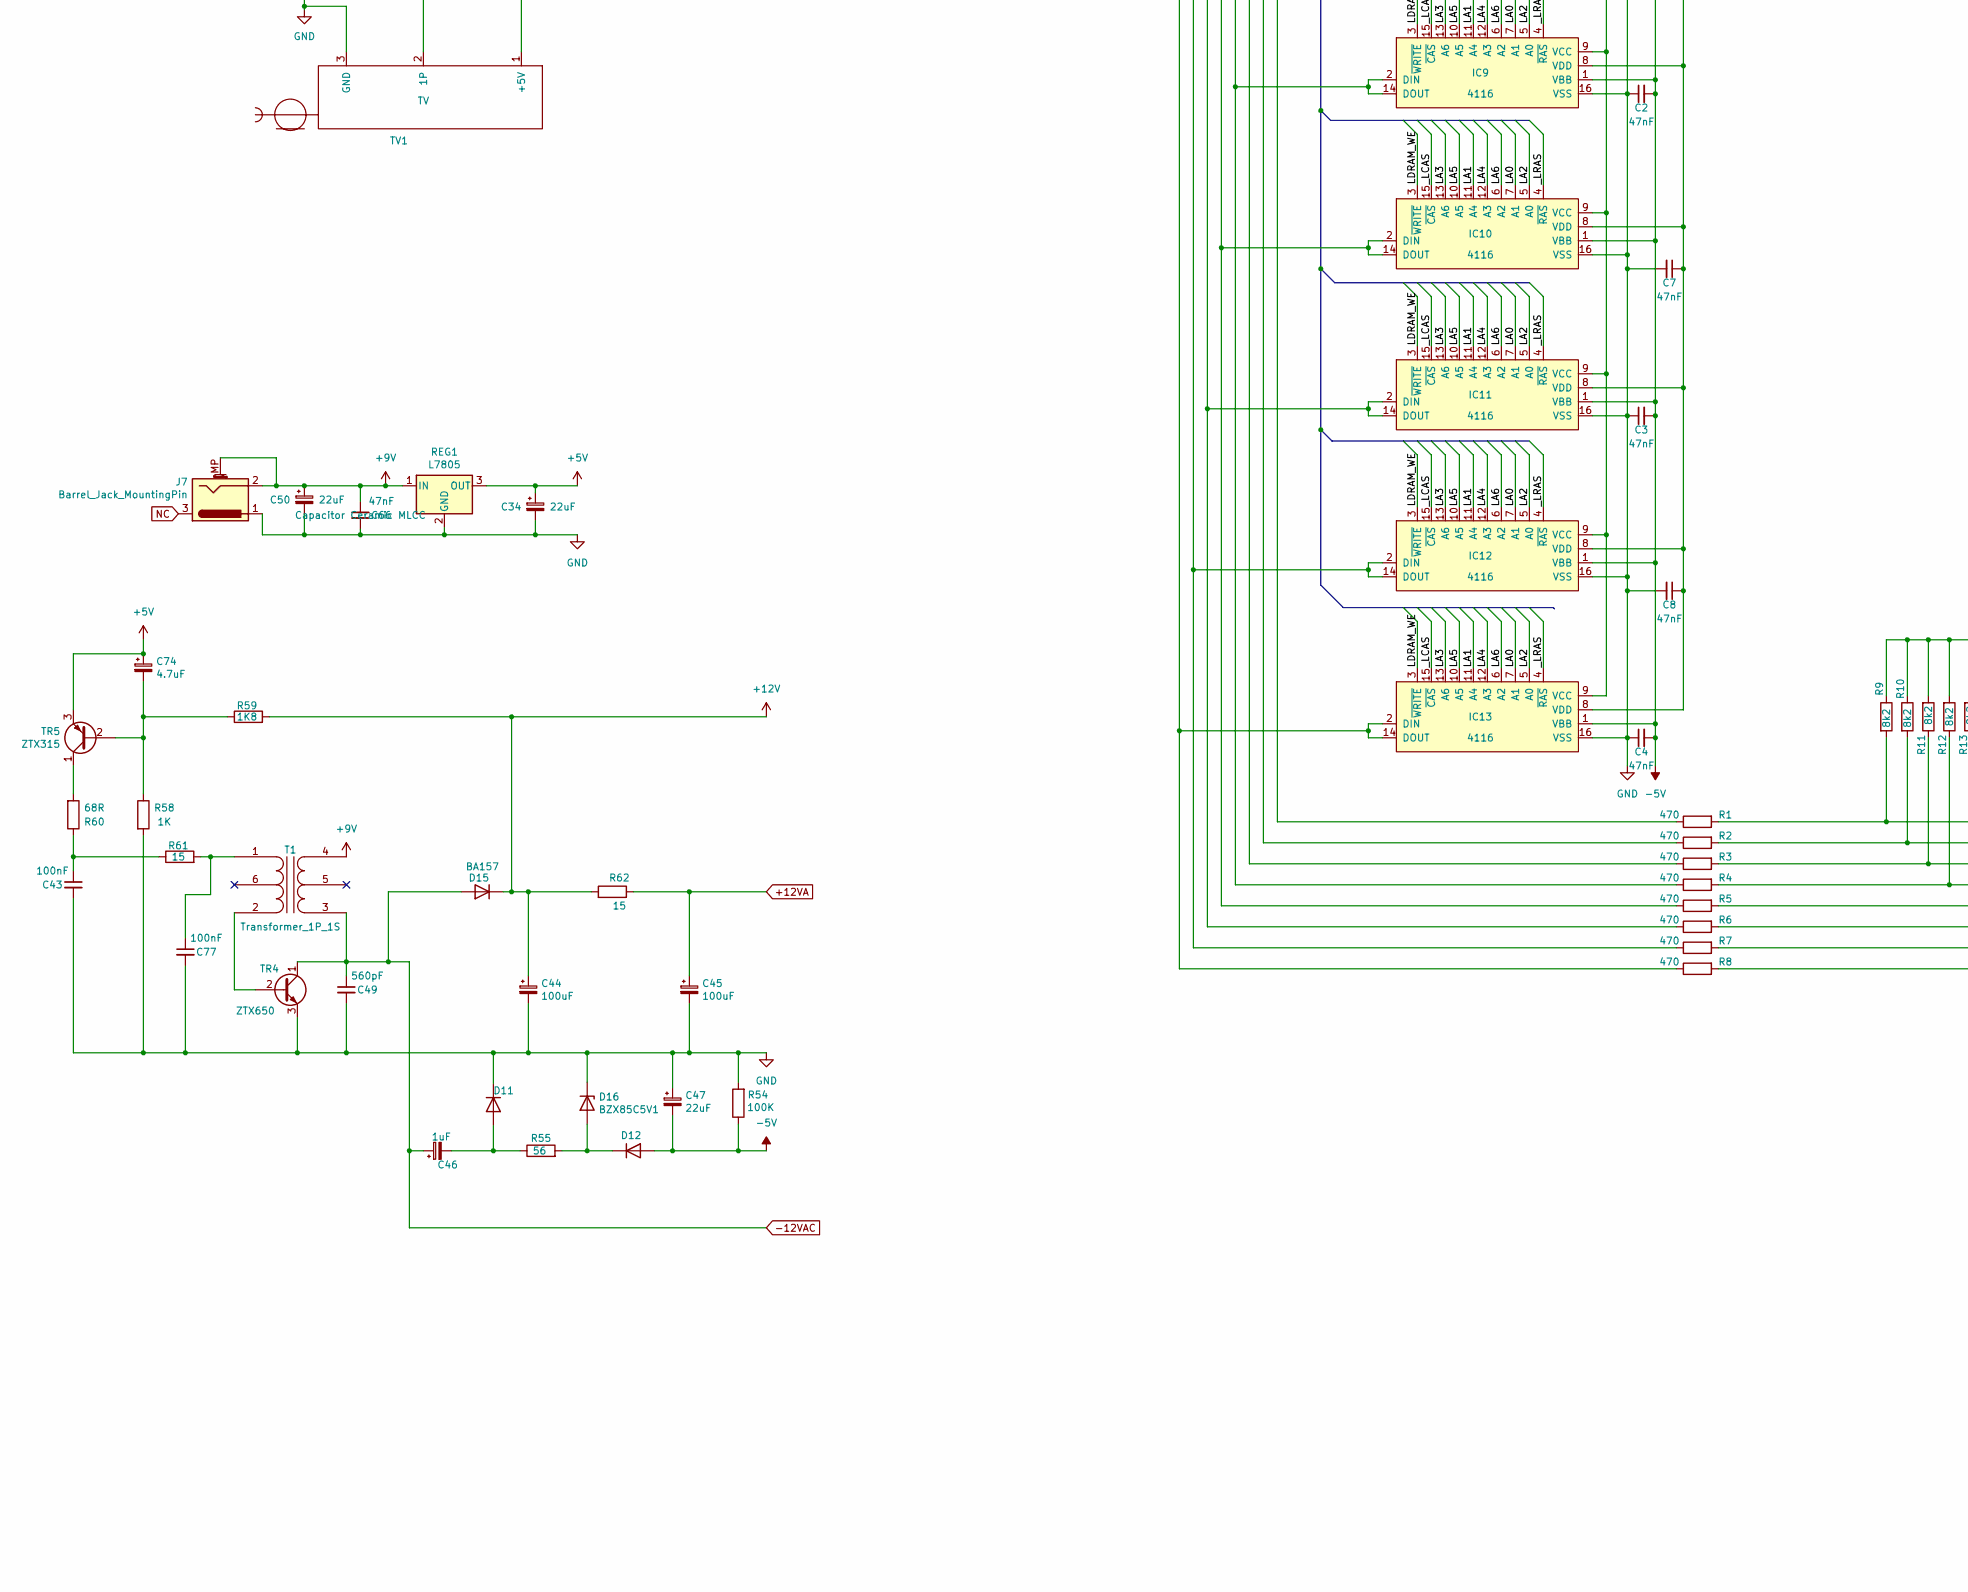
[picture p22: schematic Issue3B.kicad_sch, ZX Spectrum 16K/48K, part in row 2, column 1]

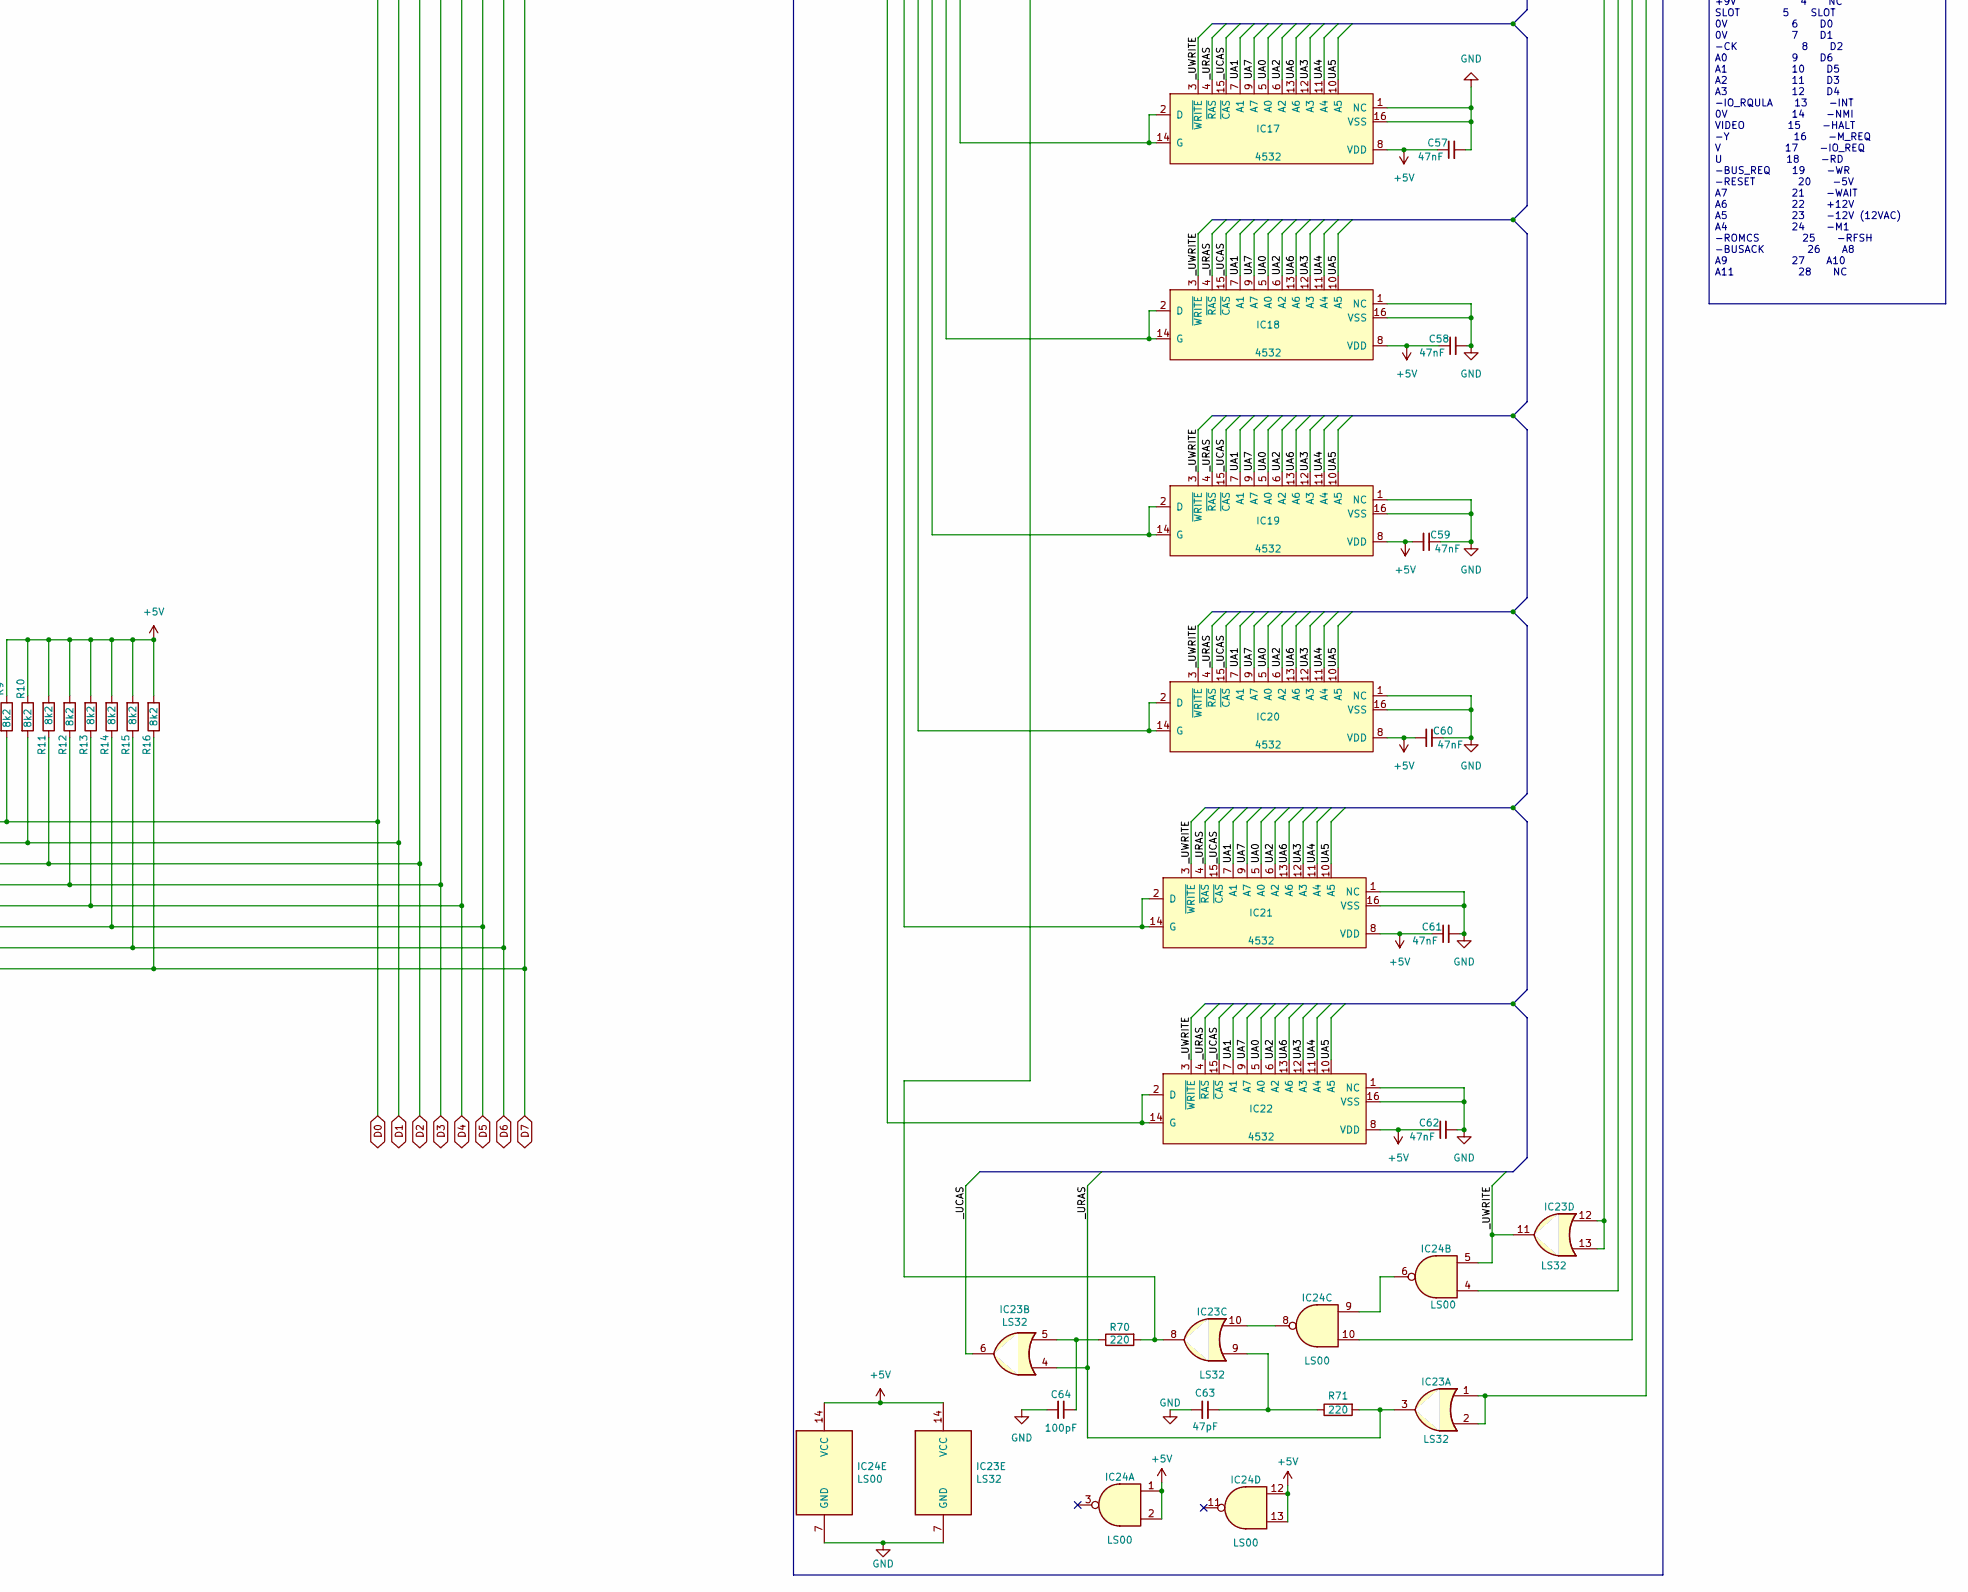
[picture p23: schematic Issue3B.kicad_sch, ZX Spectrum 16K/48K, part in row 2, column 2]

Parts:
C1, C2, C3, C4, C5, C6, C7, C8, C26, C29, C30, C33, C40, C41, C42, C48, C55, C56, C57, C58, C59, C60, C61, C62, C66, C76: 47nF; C_Axial_L3.8mm_D2.6mm_P12.70mm_Horizontal
C25: 22uF; CP_Axial_L11.0mm_D6.0mm_P20.00mm_Horizontal
C27: 1uF; CP_Axial_L11.0mm_D6.0mm_P20.00mm_Horizontal
C28, C34, C47, C50, C65: 22uF; CP_Axial_L11.0mm_D6.0mm_P20.32mm_Horizontal
C31, C32: 100nF; C_Axial_L3.8mm_D2.6mm_P12.40mm_Horizontal
C35: 10nF; C_Axial_L3.8mm_D2.6mm_P12.40mm_Horizontal
C37, C38: 33pF; C_Axial_L3.8mm_D2.6mm_P12.70mm_Horizontal
C39: 10nF; C_Axial_L3.8mm_D2.6mm_P12.70mm_Horizontal
C43, C68, C69, C70, C71, C75, C77: 100nF; C_Axial_L3.8mm_D2.6mm_P12.70mm_Horizontal
C44, C45: 100uF; CP_Axial_L11.0mm_D6.0mm_P20.32mm_Horizontal
C46: 1uF; CP_Axial_L11.0mm_D6.0mm_P20.32mm_Horizontal
C49: 560pF; C_Axial_L3.8mm_D2.6mm_P12.70mm_Horizontal
C52, C53: 150pF; C_Axial_L3.8mm_D2.6mm_P12.70mm_Horizontal
C54: 470pF; C_Axial_L3.8mm_D2.6mm_P12.70mm_Horizontal; not fitted
C63: 47pF; C_Axial_L3.8mm_D2.6mm_P12.70mm_Horizontal
C64, C67: 100pF; C_Axial_L3.8mm_D2.6mm_P12.70mm_Horizontal
C72, C73: 16pF; C_Axial_L3.8mm_D2.6mm_P12.70mm_Horizontal
C74: 4.7uF; CP_Axial_L11.0mm_D6.0mm_P20.32mm_Horizontal
D1, D2, D3, D4, D5, D6, D7, D8, D9, D11, D12: 1N4148; D_DO-35_SOD27_P12.70mm_Horizontal
D13: 1N4148; D_DO-35_SOD27_P12.40mm_Horizontal
D15: BA157; D_DO-35_SOD27_P12.70mm_Horizontal
D16: BZX85C5V1; D_DO-35_SOD27_P12.70mm_Horizontal
E1: Edge_Connector; Edge Connector
EAR1: EAR1; 3.5mm_socket
IC1: ULA; DIP-40_W15.24mm_Socket
IC2: Z80; DIP-40_W15.24mm_Socket
IC3, IC4, IC25, IC26: LS157; DIP-16_W7.62mm_Socket
IC5: ROM; DIP-28_W15.24mm_Socket
IC6, IC7, IC8, IC9, IC10, IC11, IC12, IC13: 4116; DIP-16_W7.62mm_Socket
IC14: LM1889; DIP-18_W7.62mm_Socket
IC15, IC16, IC17, IC18, IC19, IC20, IC21, IC22: 4532; DIP-16_W7.62mm_Socket
IC23: LS32; DIP-14_W7.62mm_Socket
IC24: LS00; DIP-14_W7.62mm_Socket
J7: Barrel_Jack_MountingPin; BarrelJack_Horizontal
JROM1: JROM; ROM_WireLink
KB1: Keyboard5
KB2: Keyboard8
LS1: Speaker
MIC1: MIC1; 3.5mm_socket
OKI1: OKI; WireLink
OKI-H1: OKI-H; WireLink
OKI-L1: OKI-L; WireLink
R1, R2, R3, R4, R5, R6, R7, R8, R26, R27, R78: 470; R_Yageo_L3.6mm_D1.6mm_P12.70mm_Horizontal
R9, R10, R11, R12, R13, R14, R15, R16: 8k2; R_Yageo_L3.6mm_D1.6mm_P12.70mm_Horizontal
R17, R18, R19, R20, R21, R22, R23, R57: 330; R_Yageo_L3.6mm_D1.6mm_P12.70mm_Horizontal
R24, R73: 1k; R_Yageo_L3.6mm_D1.6mm_P12.70mm_Horizontal
R25: 180; R_Yageo_L3.6mm_D1.6mm_P12.70mm_Horizontal
R28, R29, R30, R49, R65, R66, R67, R68, R69, R72, R74, R75: 10K; R_Yageo_L3.6mm_D1.6mm_P12.70mm_Horizontal
R31: 220K; R_Yageo_L3.6mm_D1.6mm_P12.70mm_Horizontal
R32: 100; R_Yageo_L3.6mm_D1.6mm_P12.70mm_Horizontal
R33: 680; R_Yageo_L3.6mm_D1.6mm_P12.70mm_Horizontal
R34: 15; R_Axial_DIN0516_L15.5mm_D5.0mm_P22.60mm_Horizontal
R35: 10K; R_Yageo_L3.6mm_D1.6mm_P12.40mm_Horizontal
R36: 680; R_Yageo_L3.6mm_D1.6mm_P12.40mm_Horizontal
R37: 1K; R_Yageo_L3.6mm_D1.6mm_P12.40mm_Horizontal
R42, R45, R46, R47, R56, R58, R63, R76, R77: 1K; R_Yageo_L3.6mm_D1.6mm_P12.70mm_Horizontal
R43: 3K; R_Yageo_L3.6mm_D1.6mm_P12.70mm_Horizontal
R44: 5K1; R_Yageo_L3.6mm_D1.6mm_P12.70mm_Horizontal
R48, R51, R52: 2K2; R_Yageo_L3.6mm_D1.6mm_P12.70mm_Horizontal
R50: 4K7; R_Yageo_L3.6mm_D1.6mm_P12.70mm_Horizontal
R53: 390R; R_Yageo_L3.6mm_D1.6mm_P12.70mm_Horizontal
R54: 100K; R_Yageo_L3.6mm_D1.6mm_P12.70mm_Horizontal
R55: 56; R_Yageo_L3.6mm_D1.6mm_P12.70mm_Horizontal
R59: 1K8; R_Yageo_L3.6mm_D1.6mm_P12.70mm_Horizontal
R60: 68R; R_Yageo_L3.6mm_D1.6mm_P12.70mm_Horizontal
R61, R62, R64: 15; R_Yageo_L3.6mm_D1.6mm_P12.70mm_Horizontal
R70, R71: 220; R_Yageo_L3.6mm_D1.6mm_P12.70mm_Horizontal
REG1: L7805; TO-220-3_Horizontal_TabDown
T1: Transformer_1P_1S; Coil
TI1: TI; WireLink
TI-3: TI-3; WireLink
TI-4: TI-4; WireLink
TR1, TR2, TR3, TR6: ZTX313; TO-92Flat
TR4: ZTX650; TO-92Flat
TR5: ZTX315; TO-92Flat
TR7: ZTX450; TO-92Flat
TR8, TR9: BC184; TR9
TV1: TV; Modulator
X1: 14Mhz; X1
X2: 4.43Mhz; X2

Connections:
+5V: C26.1, C28.1, C29.2, C34.1, C41.1, C55.1, C56.1, C57.1, C58.1, C59.2, C60.2, C61.1, C62.1, C74.1, C75.2, E1.30, IC1.14 (Vcc1), IC2.11 (VCC), IC3.16 (VCC), IC4.16 (VCC), IC5.28 (Vcc), IC6.9 (VCC), IC7.9 (VCC), IC8.9 (VCC), IC9.9 (VCC), IC10.9 (VCC), IC11.9 (VCC), IC12.9 (VCC), IC13.9 (VCC), IC15.8 (VDD), IC16.8 (VDD), IC17.8 (VDD), IC18.8 (VDD), IC19.8 (VDD), IC20.8 (VDD), IC21.8 (VDD), IC22.8 (VDD), IC23.14 (VCC), IC24.1, IC24.2, IC24.12, IC24.13, IC24.14 (VCC), IC25.16 (VCC), IC26.16 (VCC), OKI-H1.1, R9.1, R10.1, R11.2, R12.2, R13.2, R14.2, R15.2, R16.2, R25.2, R28.2, R29.2, R30.2, R31.1, R34.1, R64.2, R65.1, R66.1, R67.1, R68.1, R69.1, R73.2, R74.2, R75.2, R78.2, REG1.3 (OUT), TI-4.1, TR5.3 (E), TR6.1 (C), TR8.3 (E), TR9.3 (E)
+9V: C50.1, C66.1, E1.31, J7.2, J7.MP (MountPin), REG1.1 (IN), T1.4 (SB), TR7.1 (C)
+12V: C5.1, C6.1, C7.1, C8.1, C44.1, D15.1 (K), E1.21, IC6.8 (VDD), IC7.8 (VDD), IC8.8 (VDD), IC9.8 (VDD), IC10.8 (VDD), IC11.8 (VDD), IC12.8 (VDD), IC13.8 (VDD), R59.2, R62.2
+12VA: C33.1, C45.1, C48.1, C52.1, C53.1, IC14.14 (RF_SUPPLY), IC14.15 (SOUND_TANK), IC14.16 (CHROMA_SUPPLY), R42.1, R62.1
-5V: C1.2, C2.2, C3.2, C4.2, C47.2, D12.2 (A), E1.19, IC6.1 (VBB), IC7.1 (VBB), IC8.1 (VBB), IC9.1 (VBB), IC10.1 (VBB), IC11.1 (VBB), IC12.1 (VBB), IC13.1 (VBB), R54.1
-12VAC: C46.1, C49.1, D15.2 (A), E1.22, T1.3 (SA), TR4.1 (C)
/LA0: IC1.5 (A0), IC6.7 (A1), IC7.7 (A1), IC8.7 (A1), IC9.7 (A1), IC10.7 (A1), IC11.7 (A1), IC12.7 (A1), IC13.7 (A1), R17.1
/LA1: IC1.6 (A1), IC6.11 (A4), IC7.11 (A4), IC8.11 (A4), IC9.11 (A4), IC10.11 (A4), IC11.11 (A4), IC12.11 (A4), IC13.11 (A4), R18.1
/LA2: IC1.7 (A2), IC6.5 (A0), IC7.5 (A0), IC8.5 (A0), IC9.5 (A0), IC10.5 (A0), IC11.5 (A0), IC12.5 (A0), IC13.5 (A0), R19.1
/LA3: IC1.8 (A3), IC6.13 (A6), IC7.13 (A6), IC8.13 (A6), IC9.13 (A6), IC10.13 (A6), IC11.13 (A6), IC12.13 (A6), IC13.13 (A6), R20.1
/LA4: IC1.9 (A4), IC6.12 (A3), IC7.12 (A3), IC8.12 (A3), IC9.12 (A3), IC10.12 (A3), IC11.12 (A3), IC12.12 (A3), IC13.12 (A3), R21.1
/LA5: IC1.10 (A5), IC6.10 (A5), IC7.10 (A5), IC8.10 (A5), IC9.10 (A5), IC10.10 (A5), IC11.10 (A5), IC12.10 (A5), IC13.10 (A5), R22.1
/LA6: IC1.11 (A6), IC6.6 (A2), IC7.6 (A2), IC8.6 (A2), IC9.6 (A2), IC10.6 (A2), IC11.6 (A2), IC12.6 (A2), IC13.6 (A2), R23.1
/LDRAM_WE: IC1.4 (DRAMWE), IC6.3 (~WRITE), IC7.3 (~WRITE), IC8.3 (~WRITE), IC9.3 (~WRITE), IC10.3 (~WRITE), IC11.3 (~WRITE), IC12.3 (~WRITE), IC13.3 (~WRITE)
/UA0: IC15.5 (A0), IC16.5 (A0), IC17.5 (A0), IC18.5 (A0), IC19.5 (A0), IC20.5 (A0), IC21.5 (A0), IC22.5 (A0), IC26.7 (2Y)
/UA1: IC15.7 (A1), IC16.7 (A1), IC17.7 (A1), IC18.7 (A1), IC19.7 (A1), IC20.7 (A1), IC21.7 (A1), IC22.7 (A1), IC26.12 (4Y)
/UA2: IC15.6 (A2), IC16.6 (A2), IC17.6 (A2), IC18.6 (A2), IC19.6 (A2), IC20.6 (A2), IC21.6 (A2), IC22.6 (A2), IC26.4 (1Y)
/UA3: IC15.12 (A3), IC16.12 (A3), IC17.12 (A3), IC18.12 (A3), IC19.12 (A3), IC20.12 (A3), IC21.12 (A3), IC22.12 (A3), IC25.9 (3Y)
/UA4: IC15.11 (A4), IC16.11 (A4), IC17.11 (A4), IC18.11 (A4), IC19.11 (A4), IC20.11 (A4), IC21.11 (A4), IC22.11 (A4), IC25.7 (2Y)
/UA5: IC15.10 (A5), IC16.10 (A5), IC17.10 (A5), IC18.10 (A5), IC19.10 (A5), IC20.10 (A5), IC21.10 (A5), IC22.10 (A5), IC25.4 (1Y)
/UA6: IC15.13 (A6), IC16.13 (A6), IC17.13 (A6), IC18.13 (A6), IC19.13 (A6), IC20.13 (A6), IC21.13 (A6), IC22.13 (A6), IC25.12 (4Y)
/UA7: IC15.9 (A7), IC16.9 (A7), IC17.9 (A7), IC18.9 (A7), IC19.9 (A7), IC20.9 (A7), IC21.9 (A7), IC22.9 (A7), IC26.9 (3Y)
/_LCAS: IC1.1 (_CAS), IC6.15 (~CAS), IC7.15 (~CAS), IC8.15 (~CAS), IC9.15 (~CAS), IC10.15 (~CAS), IC11.15 (~CAS), IC12.15 (~CAS), IC13.15 (~CAS)
/_LRAS: IC1.35 (_RAS), IC6.4 (~RAS), IC7.4 (~RAS), IC8.4 (~RAS), IC9.4 (~RAS), IC10.4 (~RAS), IC11.4 (~RAS), IC12.4 (~RAS), IC13.4 (~RAS), R32.2, R57.1
/_UCAS: IC15.15 (~CAS), IC16.15 (~CAS), IC17.15 (~CAS), IC18.15 (~CAS), IC19.15 (~CAS), IC20.15 (~CAS), IC21.15 (~CAS), IC22.15 (~CAS), IC23.6
/_URAS: IC15.4 (~RAS), IC16.4 (~RAS), IC17.4 (~RAS), IC18.4 (~RAS), IC19.4 (~RAS), IC20.4 (~RAS), IC21.4 (~RAS), IC22.4 (~RAS), IC23.3, IC23.4, R71.2
/_UWRITE: IC15.3 (~WRITE), IC16.3 (~WRITE), IC17.3 (~WRITE), IC18.3 (~WRITE), IC19.3 (~WRITE), IC20.3 (~WRITE), IC21.3 (~WRITE), IC22.3 (~WRITE), IC23.11, IC24.5
A0: E1.35, IC2.30 (A8), IC4.6 (2B), IC5.10 (A0), IC26.6 (2B), TR6.2 (B)
A1: E1.36, IC2.31 (A1), IC4.3 (1B), IC5.9 (A1), IC26.3 (1B)
A2: E1.37, IC2.32 (A2), IC4.13 (4B), IC5.8 (A2), IC26.13 (4B)
A3: E1.38, IC2.33 (A3), IC3.10 (3B), IC5.7 (A3), IC25.10 (3B)
A4: E1.50, IC2.34 (A4), IC3.6 (2B), IC5.6 (A4), IC25.6 (2B)
A5: E1.49, IC2.35 (A5), IC3.3 (1B), IC5.5 (A5), IC25.3 (1B)
A6: E1.48, IC2.36 (A6), IC3.13 (4B), IC5.4 (A6), IC25.13 (4B)
A7: E1.47, IC2.37 (A7), IC4.5 (2A), IC5.3 (A7), IC26.5 (2A)
A8: D6.1 (K), E1.25, IC2.38 (A0), IC4.2 (1A), IC5.25 (A8), IC26.2 (1A)
A9: D3.1 (K), E1.53, IC2.39 (A9), IC4.14 (4A), IC5.24 (A9), IC26.14 (4A)
A10: D2.1 (K), E1.26, IC2.40 (A10), IC3.11 (3A), IC5.21 (A10), IC25.11 (3A)
A11: D1.1 (K), E1.54, IC2.1 (A11), IC3.5 (2A), IC5.23 (A11), IC25.5 (2A)
A12: D4.1 (K), E1.29, IC2.2 (A12), IC3.2 (1A), IC5.2 (A12), IC25.2 (1A)
A13: D5.1 (K), E1.2, IC2.3 (A13), IC3.14 (4A), IC5.26 (A13), IC25.14 (4A)
A14: D7.1 (K), E1.28, IC1.36 (A14), IC2.4 (A14), OKI1.2, TI1.2
A15: D8.1 (K), E1.1, IC1.37 (A15), IC2.5 (A15), IC24.10
D0: E1.5, IC2.14 (D0), IC5.11 (D0), IC15.2 (D), IC15.14 (G), R1.2, R9.2
D1: E1.6, IC2.15 (D1), IC5.12 (D1), IC16.2 (D), IC16.14 (G), R2.2, R10.2
D2: E1.7, IC2.12 (D2), IC5.13 (D2), IC17.2 (D), IC17.14 (G), R3.2, R11.1
D3: E1.10, IC2.8 (D3), IC5.15 (D3), IC18.2 (D), IC18.14 (G), R4.2, R12.1
D4: E1.11, IC2.7 (D4), IC5.16 (D4), IC19.2 (D), IC19.14 (G), R5.2, R13.1
D5: E1.9, IC2.9 (D5), IC5.17 (D5), IC20.2 (D), IC20.14 (G), R6.2, R14.1
D6: E1.8, IC2.10 (D6), IC5.18 (D6), IC21.2 (D), IC21.14 (G), R7.2, R15.1
D7: E1.3, IC2.13 (D7), IC5.19 (D7), IC22.2 (D), IC22.14 (G), R8.2, R16.1
GND: C1.1, C2.1, C3.1, C4.1, C5.2, C6.2, C7.2, C8.2, C25.2, C26.2, C27.2, C28.2, C29.1, C30.1, C33.2, C34.2, C35.1, C37.2, C40.2, C41.2, C42.2, C43.2, C44.2, C45.2, C47.1, C48.2, C49.2, C50.2, C54.2, C55.2, C56.2, C57.2, C58.2, C59.1, C60.1, C61.2, C62.2, C63.2, C64.2, C66.2, C72.2, C73.1, C75.1, C76.1, C77.2, D11.1 (K), D13.2 (A), D16.1 (K), E1.32, E1.33, E1.40, EAR1.1, IC1.40 (GND), IC2.29 (GND), IC3.8 (GND), IC3.15 (STROBE), IC4.8 (GND), IC4.15 (STROBE), IC5.14 (Vss), IC6.16 (VSS), IC7.16 (VSS), IC8.16 (VSS), IC9.16 (VSS), IC10.16 (VSS), IC11.16 (VSS), IC12.16 (VSS), IC13.16 (VSS), IC14.5 (GROUND), IC15.1 (NC), IC15.16 (VSS), IC16.1 (NC), IC16.16 (VSS), IC17.1 (NC), IC17.16 (VSS), IC18.1 (NC), IC18.16 (VSS), IC19.1 (NC), IC19.16 (VSS), IC20.1 (NC), IC20.16 (VSS), IC21.1 (NC), IC21.16 (VSS), IC22.1 (NC), IC22.16 (VSS), IC23.7 (GND), IC24.7 (GND), IC25.8 (GND), IC25.15 (STROBE), IC26.8 (GND), IC26.15 (STROBE), J7.1, LS1.1, MIC1.1, OKI-L1.1, R37.2, R43.2, R46.2, R47.1, R50.2, R52.2, R53.2, R54.2, R56.1, R58.2, R63.1, REG1.2 (GND), TI-3.1, TR3.3 (E), TR4.3 (E), TV1.3 (GND)
NC: J7.3 (MP2)
unnamed: C31.1, R35.2
unnamed: C31.2, MIC1.2
unnamed: C32.1, R36.2
unnamed: C38.1, C39.2, R46.1
unnamed: C38.2, R45.2, X2.2
unnamed: C43.1, R60.1, R61.1
unnamed: C63.1, IC23.9, R71.1
unnamed: C64.1, IC23.5, R70.1
unnamed: C72.1, R44.2, X2.1
unnamed: C73.2, X1.1
unnamed: D1.2 (A), KB2.1, KB2.11 (Pin_1A)
unnamed: D2.2 (A), KB2.2, KB2.12 (Pin_2A)
unnamed: D3.2 (A), KB2.3, KB2.13 (Pin_3A)
unnamed: D4.2 (A), KB2.4, KB2.14 (Pin_4A)
unnamed: D5.2 (A), KB2.5, KB2.15 (Pin_5A)
unnamed: D6.2 (A), KB2.6, KB2.16 (Pin_6A)
unnamed: D7.2 (A), KB2.7, KB2.17 (Pin_7A)
unnamed: D8.2 (A), KB2.8, KB2.18 (Pin_8A)
unnamed: D9.1 (K), TR7.2 (B)
unnamed: C46.2, D11.2 (A), R55.1
unnamed: D12.1 (K), D16.2 (A), R55.2
unnamed: C32.2, C35.2, D9.2 (A), D13.1 (K), IC1.28 (MIC/TAPE), R35.1
unnamed: EAR1.2, R36.1, R37.1
unnamed: IC1.18 (D0), IC6.2 (DIN), IC6.14 (DOUT), R1.1
unnamed: IC1.21 (D1), IC7.2 (DIN), IC7.14 (DOUT), R2.1
unnamed: IC1.22 (D2), IC8.2 (DIN), IC8.14 (DOUT), R3.1
unnamed: IC1.25 (D3), IC9.2 (DIN), IC9.14 (DOUT), R4.1
unnamed: IC1.27 (D4), IC10.2 (DIN), IC10.14 (DOUT), R5.1
unnamed: IC1.29 (D5), IC11.2 (DIN), IC11.14 (DOUT), R6.1
unnamed: IC1.30 (D6), IC12.2 (DIN), IC12.14 (DOUT), R7.1
unnamed: IC1.31 (D7), IC13.2 (DIN), IC13.14 (DOUT), R8.1
unnamed: IC1.19 (KB0), KB1.1, KB1.11 (A1), R69.2
unnamed: IC1.20 (KB1), KB1.2, KB1.12 (2A), R68.2
unnamed: IC1.23 (KB2), KB1.3, KB1.13 (3A), R67.2
unnamed: IC1.24 (KB3), KB1.4, KB1.14 (4A), R66.2
unnamed: IC1.26 (KB4), KB1.5, KB1.15 (5A), R65.2
unnamed: IC1.39 (OSC), X1.2
unnamed: C30.2, IC1.13 (Vcc2), R34.2
unnamed: IC1.12 (_INT), R26.1
unnamed: IC1.34 (_ROMCS), R33.2
unnamed: IC2.6 (~CLK), R25.1, TR3.1 (C)
unnamed: IC3.4 (1Y), R22.2
unnamed: IC3.7 (2Y), R21.2
unnamed: IC3.9 (3Y), R20.2
unnamed: IC3.12 (4Y), R23.2
unnamed: IC3.1 (S), IC4.1 (S), R32.1
unnamed: IC4.4 (1Y), R18.2
unnamed: IC4.7 (2Y), R17.2
unnamed: IC4.12 (4Y), R19.2
unnamed: IC5.20 (CS), JROM1.1
unnamed: IC5.27 (OE1L), JROM1.4
unnamed: C52.2, IC14.4 (B-Y_INPUT), R76.1
unnamed: C76.2, IC14.3 (CHROMA_BIAS), R78.1
unnamed: C37.1, IC14.18 (CHROMA_LAG), R45.1
unnamed: C39.1, IC14.1 (CHROMA_LEAD)
unnamed: IC14.17 (CHROMA_OSC_OUTPUT), R43.1, R44.1
unnamed: C65.1, IC14.13 (CHROMA_SUB-CARRIER), R72.2
unnamed: C53.2, IC14.2 (R-Y_INPUT), R77.1
unnamed: IC14.12 (VIDEO_INPUT), R42.2
unnamed: IC23.10, IC24.8
unnamed: IC24.6, IC24.9
unnamed: IC23.8, IC25.1 (S), IC26.1 (S), R70.2
unnamed: IC26.11 (3A), OKI-H1.2, OKI-L1.2, TI1.1
unnamed: IC26.10 (3B), OKI1.1, TI-3.2, TI-4.2
unnamed: C77.1, R61.2, T1.1 (AA)
unnamed: T1.2 (AB), TR4.2 (B)
unnamed: R48.2, R49.2, R50.1, TR1.2 (B)
unnamed: C65.2, R51.2, TR1.1 (C), TR2.2 (B)
unnamed: R52.1, TR1.3 (E)
unnamed: C25.1, C40.1, C42.1, R49.1, R51.1, R64.1, R72.1, TR2.1 (C), TV1.1 (+5V)
unnamed: C67.1, R24.1, TR3.2 (B)
unnamed: C74.2, R58.1, R59.1, TR5.2 (B)
unnamed: R60.2, TR5.1 (C)
unnamed: LS1.2, TR7.3 (E)
unnamed: C70.1, R75.1, TR8.2 (B)
unnamed: C71.1, R77.2, TR8.1 (C)
unnamed: C68.1, R74.1, TR9.2 (B)
unnamed: C69.1, R76.2, TR9.1 (C)
U: C69.2, E1.44, IC1.15 (u), R56.2
V: C71.2, E1.43, IC1.16 (v), R63.2
VIDEO: E1.41, R53.1, TR2.3 (E), TV1.2 (1P)
Y: C68.2, C70.2, E1.42, IC1.17 (h), R47.2, R48.1
_BUSACK: E1.52, IC2.23 (~BUSACK)
_BUS_REQ: E1.45, IC2.25 (~BUSRQ), R30.1
_CK: C67.2, E1.34, IC1.32 (_CPU), R24.2, R73.1
_HALT: E1.14, IC2.18 (~HALT)
_INT: E1.12, IC2.16 (~INT), R26.2
_IO_REQ: E1.16, IC2.20 (~IORQ), R27.2
_IO_RQULA: E1.39, IC1.33 (_IOREQ), R27.1, TR6.3 (E)
_M1: E1.23, IC2.27 (~M1)
_M_REQ: E1.15, IC1.38 (_MREQ), IC2.19 (~MREQ), IC23.1, IC23.2, JROM1.2
_NMI: E1.13, IC2.17 (~NMI), R28.1
_RD: E1.17, IC1.3 (_R0), IC2.21 (~RD), IC5.22 (OE0L), IC24.4
_RESET: C27.1, E1.46, IC2.26 (~RESET), R31.2
_RFSH: C54.1, E1.24, IC2.28 (~RFSH), R57.2
_ROMCS: E1.51, JROM1.3, R33.1
_WAIT: E1.20, IC2.24 (~WAIT), R29.1
_WR: E1.18, IC1.2 (_WR), IC2.22 (~WR), IC23.12, IC23.13

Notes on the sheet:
Optional 32K RAM For TI memory devices link TI and either TI-4 OR TI-3 For OKI memory devices link OKI and either OKI-H or OKI-L If fitting 64K devices, use either OKI or TI, not both.
NEC HITACHI Pin20 CE CS Pin27 CS CE
Underside Comp Side A B A14 1 A15 A13 2 A13 +5V 3 D7 +9V 4 NC SLOT 5 SLOT 0V 6 D0 0V 7 D1 -CK 8 D2 A0 9 D6 A1 10 D5 A2 11 D3 A3 12 D4 -IO_RQULA 13 -INT 0V 14 -NMI VIDEO 15 -HALT -Y 16 -M_REQ V 17 -IO_REQ U 18 -RD -BUS_REQ 19 -WR -RESET 20 -5V A7 21 -WAIT A6 22 +12V A5 23 -12V (12VAC) A4 24 -M1 -ROM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
1-2 & 3-4 = NEC 1-3 & 2-4 = Hitachi

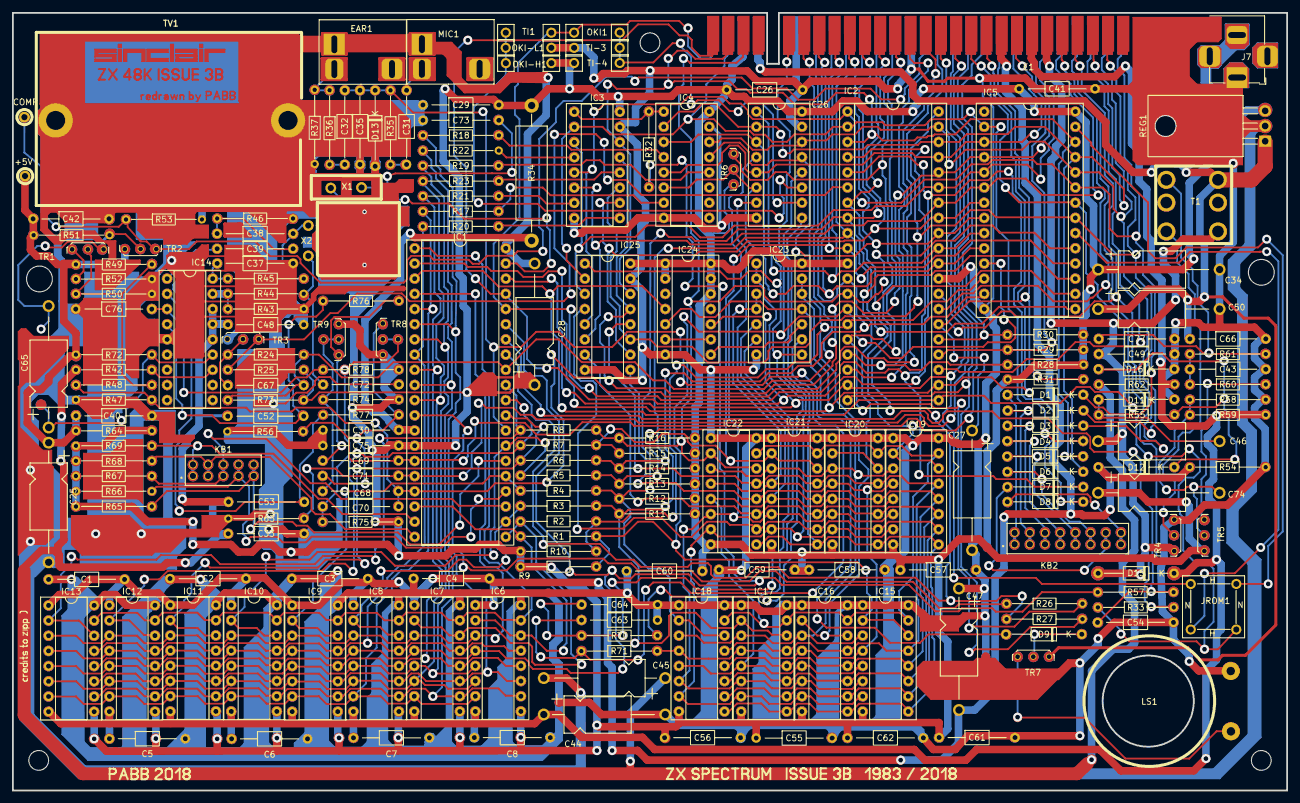
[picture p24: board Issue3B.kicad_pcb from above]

Board: 2 copper layers, 213.1 x 130.0 mm, 201 parts (0 on the bottom side), 150 nets.

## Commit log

2026-08-16 README for ZX Spectrum 48K Issue 3B
    Updated project title and expanded README with additional information about the ZX Spectrum 48K Issue 3B, including links and notes on schematic corrections and component changes.
2026-08-16 Add files via upload
    Initial Upload
    [13.34x13.34 Bobin.STEP, 22-02-3053.stp, 22-02-3083.stp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]
2026-09-27 Updated for PCB size and hole positions
    Updated for PCB size and hole positions.
    Also included stp file for the component models.
    [409HS-1K.stp, 5-520315-5.stp, AUDIO_JACK_3PIN.step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]

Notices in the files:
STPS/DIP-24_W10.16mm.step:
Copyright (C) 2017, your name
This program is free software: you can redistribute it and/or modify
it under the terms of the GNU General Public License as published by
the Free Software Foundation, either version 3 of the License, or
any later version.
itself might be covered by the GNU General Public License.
